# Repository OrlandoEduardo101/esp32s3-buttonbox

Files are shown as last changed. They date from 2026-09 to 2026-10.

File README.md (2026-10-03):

🇧🇷 Português | [🇺🇸 English](README.en.md)

# ESP32-S3 SimHub Button Box

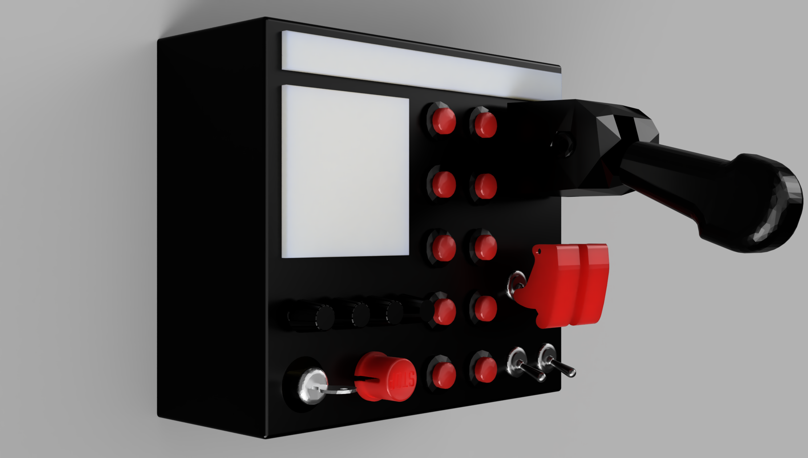
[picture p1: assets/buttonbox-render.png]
Render do button box


Button box open source (firmware + case impresso em 3D) pra sim racing:
USB HID gamepad nativo, WiFi + OTA, e integração real com o SimHub — a
placa aparece pro SimHub como um "Arduino" padrão, e **todos os efeitos de
luz são configurados dentro do próprio SimHub**, sem precisar escrever
nenhum comportamento de jogo no firmware.

## O que é este projeto

Um button box completo, do hardware ao firmware, com duas partes:

1. **Eletrônica + firmware** (este repositório): uma ESP32-S3 lê até 31
   controles físicos (botões, encoders, ignição, chaves, freio de
   estacionamento) e os expõe como um gamepad USB padrão, ao mesmo tempo
   em que fala o protocolo real do SimHub pela mesma porta serial pra
   controlar uma matriz de LEDs 8x8 (ex.: bandeiras/iFlag) e uma fita de
   LEDs (ex.: RPM).
2. **Case impresso em 3D** (pasta [`assets/`](assets)): o invólucro físico
   completo, mais pontos de fixação pra encaixar acessórios impressos por
   terceiros (freio de estacionamento, botão de rádio PTT) — ver seção
   abaixo.

## Recursos principais

- **HID nativo** (USB-OTG/TinyUSB) — aparece como gamepad no Windows sem
  driver nenhum, 32 botões.
- **WiFi + OTA** — depois da primeira gravação por cabo, todo o resto é
  sem fio.
- **Protocolo Arduino real do SimHub** — incluindo a camada de transporte
  ARQ (checksum + confirmação por pacote) que o scanner da aba "Arduino"
  do SimHub realmente usa, não um sketch de LED simplificado.
- **RGB Matrix (8x8) + RGB Leds (fita)** — dois dispositivos lógicos
  separados pro SimHub, numa única cadeia física de LEDs endereçáveis.
  Nenhuma lógica de jogo no firmware: o SimHub decide as cores, o
  firmware só recebe e acende.
- **Pinout 100% centralizado e configurável** — trocar de placa ESP32 ou
  reaproveitar este projeto com outro pinout é editar um arquivo só (ver
  abaixo).
- **Sem matriz de botões** — cada entrada tem canal/pino próprio,
  priorizando confiabilidade e simplicidade de fiação.
- **Case open source** — impresso em 3D, com pontos pra parafusar
  acessórios de terceiros.

## Hardware eletrônico

| Componente | Função |
|---|---|
| ESP32-S3 (qualquer variante com USB-OTG nativo) | MCU — HID, WiFi, OTA, protocolo SimHub |
| MCP23017 (I2C) | CLK/DT dos 4 encoders (quadratura, amostrada 1 kHz), SW dos 4 encoders, 4 chaves "caça" |
| 74HC4067 (mux 16 canais) | 11 push buttons, ignição (3 posições), botão Start Engine, freio de estacionamento |
| 4× encoder KY-040 | CLK/DT e SW pelo MCP23017 (nenhum fio direto na MCU) |
| Matriz WS2812 8x8 (64 LEDs) | RGB Matrix do SimHub — ex.: iFlag |
| Fita WS2812 (~12 LEDs, configurável) | RGB Leds do SimHub — ex.: RPM |

## Case impresso em 3D

Tudo em [`assets/`](assets):

| Arquivo | Conteúdo |
|---|---|
| `assets/STL/front.stl` | Painel frontal |
| `assets/STL/rear.stl` | Painel traseiro |
| `assets/STL/stand.stl` | Base/suporte |
| `assets/STL/LED holder.stl` | Suporte da matriz/fita de LED |
| `assets/buttonbox.f3z` | Projeto Fusion 360 completo, editável (arquivo grande — ver nota abaixo) |

> **Nota sobre o `buttonbox.f3z`**: esse arquivo tem ~124 MB, acima do
> limite de 100 MB que o GitHub aceita sem Git LFS configurado no
> repositório. Ele ainda não está versionado aqui — se você precisar do
> projeto Fusion 360 editável, pergunte ou acompanhe o repositório pra
> essa parte ser resolvida (Git LFS, ou hospedagem externa).

### Acessórios de terceiros compatíveis

Estes não são meus — são projetos separados de outros criadores, feitos
pra combinar com este button box. Baixe, imprima e parafuse direto no
case:

- **[Freio de estacionamento DIY para truck simulators](https://www.printables.com/model/995554-diy-parking-brake-for-truck-simulators/files)**
  (Printables) — a alavanca física que aciona o `INPUT_HANDBRAKE`
  (ver [`docs/INPUTS_PINOUT.md`](docs/INPUTS_PINOUT.md) seção 7 pra como o
  firmware trata esse sinal).
- **Botão de rádio (PTT)** — duas opções no Thingiverse:
  [thing:4740146](https://www.thingiverse.com/thing:4740146) e
  [thing:2928122](https://www.thingiverse.com/thing:2928122).

Confira a licença e os créditos de cada modelo na própria página do
autor antes de usar/redistribuir.

## Por que dá pra reaproveitar isso pra outra placa/pinout

Todo pino, canal e endereço deste projeto está centralizado em
**[`include/board_config.h`](include/board_config.h)** — é o único arquivo
que muda se você trocar de placa ESP32 (maior, outra variante) ou só
quiser usar pinos diferentes. Nenhum outro `.cpp`/`.h` tem número de pino
"solto" no meio do código.

Os drivers de cada componente (`lib/mcp23017`, `lib/mux4067`,
`lib/encoders`, `lib/ws2812`) são genéricos e continuam funcionando
sozinhos, fora deste projeto — cada um aceita pino/endereço como parâmetro
e só usa um valor default próprio se você não passar nada.

## Arquitetura (visão geral)

```
                    ESP32-S3
                       │
        ┌──────────────┼───────────────┐
        │              │               │
       HID            CDC             WiFi
        │              │               │
        │           SimHub            OTA
        │              │
        │         RGB framebuffer
        │              │
        │              ▼
        │           WS2812 (matriz + fita, em série)
        │
        ▼
      INPUTS
        │
   Expansores (task dedicada faz o polling)
   ┌────┴────┐
   │         │
MCP23017   74HC4067
   │         │
   └─────────┴── controles físicos
```

Cada seta é uma camada independente — nenhuma conhece a lógica da outra
(ex.: o driver WS2812 não sabe o que é RPM; o parser do SimHub não sabe o
que é GPIO). Detalhe completo, com a auditoria de cada regra de
isolamento, em [`docs/SYSTEM_INTEGRATION.md`](docs/SYSTEM_INTEGRATION.md).

## Como compilar e gravar

1. **`secrets.h`** (obrigatório, não versionado — só o hostname OTA, sem
   WiFi):
   ```
   cp include/secrets.h.example include/secrets.h
   ```
   Não precisa editar nada pra WiFi funcionar — ver o passo 4 abaixo.

2. **Pinout** (só se sua fiação for diferente do padrão): edite
   [`include/board_config.h`](include/board_config.h).

3. **Compilar + gravar por USB** (primeira vez, ou sem WiFi disponível):
   ```
   pio run -e esp32s3-supermini -t upload
   ```
   Não precisa segurar nenhum botão — o firmware entra em modo download
   sozinho (ver `scripts/enter_bootloader.py`).

4. **Configurar o WiFi** (nenhuma credencial fica no código/repositório):
   segure o botão **BOOT** da placa por 5s — ou, com a caixa fechada,
   **Push button 1 + Push button 2** juntos por 5s. Abre um Access Point
   `ButtonBox-Setup`; conecta nele do celular/PC e escolhe a rede. Fica
   salvo no NVS da própria placa, sobrevive a reboot. Pode repetir esse
   gesto a qualquer momento pra trocar de rede (ex.: levou a button box pra
   outra casa).

5. **Gravar por OTA** (depois da primeira vez, com WiFi já configurado):
   ```
   pio run -e ota -t upload
   ```

## Como testar cada peça isoladamente

Cada componente de hardware tem um firmware de teste próprio, sem HID/
WiFi/OTA/SimHub misturado — grava, conecta só aquele componente, e
confirma que funciona antes de integrar com o resto:

| Env | Testa | Comando |
|---|---|---|
| `mcp-test` | MCP23017 (16 entradas) | `pio run -e mcp-test -t upload -t monitor` |
| `mux-test` | 74HC4067 (canais configurados) | `pio run -e mux-test -t upload -t monitor` |
| `encoder-test` | Os 4 KY-040 (CW/CCW) | `pio run -e encoder-test -t upload -t monitor` |
| `inputs-test` | Camada unificada (os três juntos) | `pio run -e inputs-test -t upload -t monitor` |
| `ws2812-test` | Matriz + fita (varredura de cores) | `pio run -e ws2812-test -t upload -t monitor` |
| `simhub-test` | Protocolo SimHub isolado | `pio run -e simhub-test -t upload` + `python scripts/simhub_test_send.py <porta>` |
| `diag` | Toolchain/board mínimo (sem HID) | `pio run -e diag -t upload -t monitor` |

Se o firmware completo (`esp32s3-supermini`) apresentar algum problema,
comece isolando pelo teste do componente suspeito — é mais rápido achar a
causa assim do que depurar tudo junto.

## Console serial (CDC)

Além do protocolo do SimHub, a mesma porta COM aceita comandos de texto
(qualquer terminal serial, 115200 baud):

| Comando | Efeito |
|---|---|
| `PING` | responde `PONG` |
| `VERSION` | versão do firmware |
| `IP` | IP atual na rede |
| `SETLEDS <n>` | define quantos LEDs tem a fita (persiste em NVS) |
| `DUMPLEDS` | mostra o que os framebuffers da matriz/fita têm agora |
| `BOOTLOADER` | entra em modo download por software (sem precisar do botão BOOT) |

## Documentação completa

| Arquivo | Conteúdo |
|---|---|
| [`docs/ARCHITECTURE.md`](docs/ARCHITECTURE.md) | USB (VID/PID/descriptors), HID, CDC, WiFi, OTA — como cada peça do baseline funciona |
| [`docs/BASELINE.md`](docs/BASELINE.md) | Testes que comprovadamente passaram, com evidência |
| [`docs/INPUTS_PINOUT.md`](docs/INPUTS_PINOUT.md) | Por que cada entrada foi pro MCP23017/74HC4067/GPIO direto (o raciocínio; os números atuais estão em `board_config.h`) |
| [`docs/SIMHUB_PROTOCOL.md`](docs/SIMHUB_PROTOCOL.md) | Protocolo real do SimHub (transporte ARQ + comandos), com os erros de investigação registrados de propósito |
| [`docs/SYSTEM_INTEGRATION.md`](docs/SYSTEM_INTEGRATION.md) | Integração final, auditoria de isolamento entre camadas, checklist de teste completo |
| [`HANDOFF.md`](HANDOFF.md) | Histórico do projeto (incluindo a tentativa anterior com STM32, abandonada por hardware clonado) |

## Não implementado por decisão explícita

- Nenhuma lógica de jogo no firmware (RPM, flags, shift light, pit
  limiter) — o SimHub decide tudo, o firmware só recebe RGB e acende.
- `SHCustomProtocol` do SimHub — não usado; a placa aparece como um
  dispositivo "Arduino" padrão, configurável inteiramente pela UI do
  SimHub.
- Matriz de botões — cada entrada tem canal/pino próprio.

## ☕ Apoie este projeto

Se este projeto te ajudou ou economizou seu tempo, você pode apoiar:

- PicPay: **@orlandoeduardo.pereira**
- Link: https://picpay.me/orlandoeduardo.pereira
- Link (PicPay): https://link.picpay.com/p/177377918669b9b8f2b4e25

QR Code PIX:

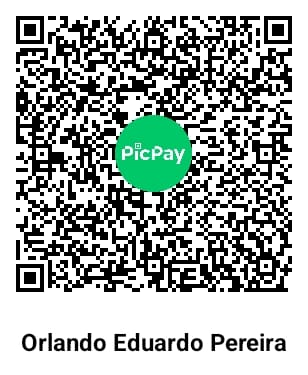
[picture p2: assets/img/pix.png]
QR Code PIX do PicPay


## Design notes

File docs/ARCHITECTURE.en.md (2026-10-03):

[🇧🇷 Português](ARCHITECTURE.md) | 🇺🇸 English

# ARCHITECTURE.md — Verified current state (post-stage-5 baseline)

> This document describes the firmware **exactly as it exists right now**, with
> no code changes made during this audit. Every fact here is
> verified by direct reading of this project's source code, of the installed
> Arduino-ESP32 core (`~/.platformio/packages/framework-arduinoespressif32`)
> and/or of `compile_commands.json` (macros actually used in the last
> compilation) — never by assumption or by trusting the Windows screen alone
> (which can have stale driver cache, as we've seen before).
>
> Generated on 2026-09-15. If the code changes after this date, this document
> may become outdated — treat it as a snapshot, not a live source.

---

## 1. How the device shows up in Windows

When connected via USB, Windows enumerates **a single composite USB device**
with two functions (interfaces), recognized by two different drivers:

- **`joy.cpl` (Game controllers)**: shows up as `ESP32S3-SimHub-ButtonBox`,
  status OK, with **32 buttons** and **4 axes** (X, Y, Z, Z-Rotation, X-Rotation,
  Y-Rotation — 6 axes declared in the descriptor, but `main.cpp` only uses the
  button bitmask; axes always stay at 0). Button 32 blinks on its own
  The Button 32 is free — the heartbeat that used to blink on it was removed
  (see item 9).
- **COM port (Device Manager → Ports)**: shows up with the same
  product name, assigned by Windows' standard serial driver (`usbser.sys`),
  usable from any serial terminal (VS Code Serial Monitor, PuTTY, etc.) at
  115200 baud.

Confirmed by a real screenshot from the user (joy.cpl with 32 dots, button
32 lit) and by a Serial Monitor session responding to text commands.

## 2. VID/PID

- **VID = `0x303A`** (Espressif Systems) — fixed, comes from the core (`USB_ESPRESSIF_VID`
  in `esp32-hal-tinyusb.h`), never overridden in this project.
- **PID = `0x1001`** — comes from `variants/esp32s3/pins_arduino.h`
  (`#define USB_PID 0x1001`), which is included **before** the fallback in
  `USB.cpp` (`#ifndef USB_PID #define USB_PID 0x0002`). Since this project's
  board.json uses `"variant": "esp32s3"`, the variant's define wins and the
  app enumerates as **`303A:1001`**.

  > **CORRECTION (2026-09-16).** The previous version of this document claimed
  > the PID was `0x0002` and that any `303A:1001` seen in a `device
  > list` would be "the separate USB-Serial-JTAG interface". **Both
  > claims were wrong.** The mistake came from checking only
  > `compile_commands.json` (where indeed there's no `-DUSB_PID`) and concluding
  > from that, without checking the variant's header. Practical consequence:
  > seeing `303A:1001` on a port does **not** mean the board is in
  > bootloader mode — it's the app running normally.

## 3. Manufacturer

`SimRacing_DIY` — explicitly defined in `platformio.ini`:
```
-DUSB_MANUFACTURER=\"SimRacing_DIY\"
```
Without this flag, the core would use the default `"Espressif Systems"`.

## 4. Product

`ESP32S3-SimHub-ButtonBox` — explicitly defined in `platformio.ini`:
```
-DUSB_PRODUCT=\"ESP32S3-SimHub-ButtonBox\"
```
Without this flag, the core would default to the `ARDUINO_BOARD` macro, which
PlatformIO automatically injects from the `"name"` field in
`boards/esp32-s3-fh4r2.json` (`"ESP32-S3-FH4R2 (Dingyimei S3 Zero)"`) — this was
exactly the leak that caused the odd name in `joy.cpl` before this
fix (already applied and confirmed, part of the current baseline).

## 5. Serial Number

Not fixed in code — it's **automatically derived from the chip's MAC address**
at runtime. Mechanism (`USB.cpp`, `ESPUSB::begin()`):
```
USB_SERIAL default = "__MAC__"
  -> if (serial_number == "__MAC__"): reads esp_efuse_mac_get_default(),
     formats as "%02X%02X%02X%02X%02X%02X" (12 uppercase hex chars)
```
For the board used in testing (MAC `AC:27:6E:CC:FA:B8`), the observed serial is
`AC276ECCFAB8` — matches the formula above exactly.

`platformio.ini` also uses this MAC (`custom_expected_mac`,
`custom_board_mac`) for the port auto-detection scripts — see items 12
and 15.

## 6. USB Interfaces

Composite TinyUSB device with `ARDUINO_USB_MODE=0` (native USB-OTG) and
`ARDUINO_USB_CDC_ON_BOOT=1`:

- **HID interface** — HID class, one interrupt IN endpoint. Gamepad
  reports (see item 7).
- **CDC ACM interface** (2 sub-interfaces: Control + Data, like any standard
  TinyUSB CDC) — virtual serial port, used for text commands and
  logs (see item 10).

There's no hand-written composite descriptor in this project (unlike
the earlier STM32 project, where `usb_descriptors.c` assembled everything manually) —
here the Arduino-ESP32 core assembles the descriptor automatically based on which
classes (`USB.begin()`, `USBHIDGamepad`, `USBCDC` via `ARDUINO_USB_CDC_ON_BOOT`)
get initialized in `setup()`.

## 7. HID report descriptor

Comes ready-made from the Arduino-ESP32 core (`libraries/USB/src/USBHIDGamepad.cpp`), via
TinyUSB's standard template:
```c
static const uint8_t report_descriptor[] = {
    TUD_HID_REPORT_DESC_GAMEPAD(HID_REPORT_ID(HID_REPORT_ID_GAMEPAD))
};
```
Not a single byte of this descriptor is customized in this project — it's TinyUSB's
standard `TUD_HID_REPORT_DESC_GAMEPAD` template (`class/hid/hid_device.h`), with
**Report ID = 3** (`HID_REPORT_ID_GAMEPAD`, the 4th value in the enum
`HID_REPORT_ID_NONE=0, KEYBOARD=1, MOUSE=2, GAMEPAD=3` in `USBHID.h`).

Report layout (`hid_gamepad_report_t` struct, 8 bytes + 1 Report ID byte):

| Field | Size | Type | Use in firmware |
|---|---|---|---|
| Report ID | 1 byte  | — | always `3`, implicit |
| X | 1 byte  | int8 | always `0` (unused) |
| Y | 1 byte  | int8 | always `0` (unused) |
| Z | 1 byte  | int8 | always `0` (unused) |
| Rz | 1 byte  | int8 | always `0` (unused) |
| Rx | 1 byte  | int8 | always `0` (unused) |
| Ry | 1 byte  | int8 | always `0` (unused) |
| Hat/DPad  | 1 byte  | uint8  | always `0` (centered, unused)  |
| Buttons | 4 bytes | uint32 | bitmask, bit N = button N+1 |

`main.cpp` only uses the last field:
```cpp
Gamepad.send(0, 0, 0, 0, 0, 0, 0, buttons);
//           x  y  z  rz rx ry hat  buttons
```
The 6 axes and the hat exist because they're part of TinyUSB's fixed template —
there's no way to omit them without writing a custom descriptor (which this
project doesn't do). That's why `joy.cpl` shows axes parked at zero.

## 8. Number of buttons currently exposed

**UPDATED** since the original version of this document (2026-09-15): the
unified `lib/inputs` layer was integrated into HID, replacing the
simulated values. **32 buttons** in the descriptor (`uint32_t buttons`, bits
0–31, `HID_REPORT_COUNT(32)`, unchanged), of which:

- **Bits 0–30 (Buttons 1–31)** = the 31 real Button Box controls
  (MCP23017 + 74HC4067 + 4× KY-040), via `lib/inputs`. Full map
  (INPUT LOGICAL ID → bit) in `docs/INPUTS_PINOUT.en.md` section 10.
- **Bit 31 (Button 32)** = **free**. It used to be the bring-up heartbeat,
  removed as soon as the 31 real controls started responding on the bench. It
  is the first slot available for a new control.

The old "Bit 0 = board's BOOT button" was removed — it was a
simulated bring-up value, replaced by the real `INPUT_BUTTON_01` (MCP23017).
The physical BOOT button still exists only to open the WiFi portal
(hold for 5s), with no more connection to HID.

## 9. The button-32 heartbeat — removed

**It no longer exists in the firmware.** Throughout bring-up, bit 31 toggled on
its own every 1 s, purely in software via `millis()`, with no dependency on
WiFi/OTA/interrupts and no wiring at all:

```cpp
// REMOVED — kept here only as a reusable technique
if (now - lastBeatMs >= 1000) {
  lastBeatMs = now;
  beatOn = !beatOn;
  if (beatOn) buttons |= (1UL << 31);
  else        buttons &= ~(1UL << 31);
}
```

It was a proof of life for the HID before any hardware existed: if Button 32
blinked in `joy.cpl`, then USB, the descriptor and report sending were fine, and
any problem was wiring.

It went away once the 31 real controls started responding. Keeping it would be
noise: a button that fires by itself every second is exactly the kind of thing a
game or SimHub binds by mistake during auto-learn.

It is worth pasting the snippet back temporarily when bringing up a **new
board** — it is the cheapest test there is, and needs nothing soldered.

## 10. How the CDC is used

The CDC (COM port) is used only for a simple line-by-line text console,
processed in `serialCommands()`:

| Command | Response / effect |
|---|---|
| `PING` | replies `PONG` |
| `VERSION` | replies `ESP32S3_BUTTONBOX_HID_OTA` |
| `IP` | replies with the current IP (`WiFi.localIP()`) |
| `RSSI` | replies `RSSI <dBm> sleep=<ON\|OFF> ip=<ip>`, or `RSSI_OFFLINE`. Link diagnostic: `-50` great, `-67` is the practical floor for reliable OTA, below `-75` OTA breaks. `sleep=ON` together with a flaky OTA is a firmware bug, not a network one |
| `SETLEDS <n>`| sets the number of LEDs on the **strip** (1-192, default 12; the matrix is fixed at 64). Persisted in NVS. Replies `LEDS_SET <n>` or `LEDS_INVALID (1-192)` |
| `BRIGHTNESS` | replies `BRIGHTNESS_GET <n>%` (query only) |
| `BRIGHTNESS <n>` | caps global LED brightness. Clamped to 25-75%, so `BRIGHTNESS 10` replies `BRIGHTNESS_SET 25%` without an error; it only rejects outside 1-100. Persisted in NVS |
| `DUMPLEDS` | prints what arrived from SimHub (matrix and strip) without needing the physical LEDs lit |
| `WATCH` | toggles input-transition logging. Every press prints the **logical name** of the `InputId` (e.g. `[watch] INPUT_BUTTON_03  PRESSIONADO`). Use it to find a swapped wire without a multimeter: pressing button 4 and getting `INPUT_BUTTON_03` proves the wire is on the wrong channel. Off by default |
| `LED` | shows `gpio`, `override` and the ignition state the firmware reads |
| `LED 1` / `LED 0` | forces the Start Engine LED, ignoring the key — isolates firmware from wiring |
| `LED AUTO` | hands LED control back to the ignition |
| `BOOTLOADER` | replies `REBOOTING_TO_BOOTLOADER`, then enters download mode via `usb_persist_restart(RESTART_BOOTLOADER)` — see item 15 for why this is **no longer** a direct `REG_WRITE` |

It also emits periodic unsolicited logs (`statusReport()`, every 5s):
WiFi/OTA/portal status. **During an OTA upload (`otaRunning == true`), the CDC
is not used for anything** — no writes happen, on purpose (see item 12).

Commands are case-insensitive (converted to uppercase before `strcmp`),
terminated by `\n` (32-byte buffer, `\r` ignored).

## 11. How WiFi connects

**No hardcoded credential (changed Oct/2026).** Always station mode (STA),
but `WiFi.begin()` is called **with no arguments** — this reconnects to the
last network saved in the ESP32's own NVS (persisted automatically on every
successful `WiFi.begin(ssid, pass)`, including what the config portal does
internally). On a never-configured board this simply doesn't connect (empty
NVS) until someone opens the portal once — deliberate: no network is fixed
in the firmware or the repo, so anyone reusing this project (or moving
houses/networks, as actually happened in practice) configures their own
network through the portal alone, with no code or `secrets.h` edit:

```cpp
// setup()
WiFi.mode(WIFI_STA);
WiFi.setAutoReconnect(true);
WiFi.begin(); // last network saved in NVS, no credential in the code
```

If the connection drops or never comes up, `wifiKeepAlive()` (called every
`loop()`, but throttled to 1 attempt every 10s) calls `WiFi.disconnect()` +
`WiFi.begin()` again (same no-argument call), **forever, without giving up
and without opening the portal on its own**. This is deliberate (comment at
the top of `main.cpp`): an earlier version opened the config portal
automatically on every failure and the board got stuck in AP mode, offline,
never reconnecting again.

The config portal (`WiFiManager`, for switching/registering the network
without recompiling or editing `secrets.h`) only opens on explicit request,
**two** ways:
- holding the board's **BOOT** button for 5 seconds **during normal
  operation** (not at boot — GPIO0 low at reset enters download mode and
  the app never even runs);
- with the **case closed** (no access to BOOT): holding **Push button 1 +
  Push button 2** together for 5 seconds. Any button combo works as long as
  it doesn't include Push button 11 (it's the radio PTT — pressed
  frequently during normal use, can't be part of a "hold for 5s" gesture).

```cpp
// src/main.cpp — same function for both gestures
static void startWifiPortal() {
  wm.setConfigPortalBlocking(false);
  wm.startConfigPortal(AP_NAME);  // AP_NAME = "ButtonBox-Setup"
  portalAtivo = true;             // do NOT use the return value — see note below
}
```

**Bug fixed (Oct/2026):** `startConfigPortal()` in non-blocking mode always
returns `false` immediately (it only enters the blocking loop when
configured blocking, which isn't the case here). Assigning that return
value directly to `portalAtivo` made `loop()` never call `wm.process()` —
the portal's AP would come up (SSID visible) but the config page never
responded, because the DNS/HTTP handler only runs inside `wm.process()`.
Now `portalAtivo` is set to `true` unconditionally, and only goes back to
`false` once `wm.process()` returns `true` (new network connected
successfully).

`WiFi.setSleep(false)` is only called inside `startOta()`, **after**
`WiFi.begin()` has already been called in `setup()` — calling it before, with the
radio not yet initialized in STA, prevents the AP portal from coming up (a lesson
documented at the top of the file).

## 12. How OTA is started

`ArduinoOTA` + `ESPmDNS`, initialized once by `startOta()`,
called from `loop()` only when WiFi is connected:
```cpp
void loop() {
  if (WiFi.status() == WL_CONNECTED) startOta();
  if (otaReady) ArduinoOTA.handle();
  if (otaRunning) return;   // nothing else runs during upload
  ...
}
```
`startOta()` is guarded by `otaReady` (only runs once): registers the hostname
(`OTA_HOSTNAME`, from `secrets.h`), `onStart`/`onEnd`/`onError` callbacks, and
**deliberately no `onProgress` callback** — writing to the CDC during
the upload blocks when the host isn't reading the port, which used to stall
`ArduinoOTA.handle()` and kill the transfer halfway through (this was the cause of
the old "Error Uploading" at ~29%, resolved before this baseline).

Once the OTA upload starts (`otaRunning = true` in `onStart`), the
`loop()` returns early right after calling `ArduinoOTA.handle()` — no
other logic (HID, serial, WiFi keep-alive) runs until the upload finishes.

## 13. How the firmware is updated

Two paths, both via the same `platformio.ini`:

- **USB (cable)**: `pio run -e esp32s3-supermini -t upload`. The
  `extra_scripts = pre:scripts/enter_bootloader.py` runs before the upload:
  finds the board's port by MAC (`custom_expected_mac`), opens it with
  `dtr=False, rts=False`, sends `BOOTLOADER\n` (the same command from item 10),
  waits up to 10s for a new port in download mode, and repoints
  `UPLOAD_PORT` to it. **Doesn't require manually holding the BOOT button** —
  this was already a problem resolved before this baseline.
- **OTA (WiFi)**: `pio run -e esp32s3-ota -t upload` (env `[env:ota]`, which
  extends `esp32s3-supermini` with `upload_protocol = espota`). The
  `extra_scripts = pre:scripts/ota_port_by_mac.py` discovers the board's current
  IP by MAC (`arp -a` after a broadcast ping) and replaces
  `UPLOAD_PORT` with it — works around the fact that `espota` doesn't resolve
  `.local` (mDNS) names and the IP can change via DHCP.

In both cases, the binary is uploaded to the idle OTA partition (`ota_0`/`ota_1`,
1.25 MB each, see `default.csv`) and the bootloader switches to it on the next
boot — there's no need to erase the entire flash.

## 14. Which PlatformIO board/env should be used

- **Board**: `esp32-s3-fh4r2` (`boards/esp32-s3-fh4r2.json`, custom, **not** the
  generic `esp32-s3-devkitc-1`) — 4 MB flash + 2 MB quad PSRAM
  (`memory_type=qio_qspi`), `default.csv` partitions. Using the generic devkit
  (8 MB, without this PSRAM) causes a **boot loop** on this physical board (history
  documented in `HANDOFF.md`).
- **Env for normal development (compile + flash + run)**:
  `[env:esp32s3-supermini]` — the only one with the production firmware
  (`src_filter = +<main.cpp>`), full HID + CDC + WiFi + OTA.
- **`[env:diag]` env**: an alternative minimal firmware (`src/diag.cpp`,
  `ARDUINO_USB_MODE=1`, just prints `"alive N"` every 500 ms). Exists only to
  isolate toolchain/board/flashing problems from the HID logic — **not the
  product firmware**, exposes no HID at all.
- **`[env:ota]` env**: the same firmware as `esp32s3-supermini` (via `extends`),
  just swaps the upload protocol to WiFi.

## 15. Which files are critical and shouldn't be changed without need

| File | Why it's critical |
|---|---|
| `src/main.cpp` | All the HID, WiFi, OTA, and serial console logic. Contains, in comments at the top and around the `BOOTLOADER` command, the history of already-resolved bugs (stuck portal, `setSleep` before `begin`, CDC writes stalling OTA, RTC register stuck in bootloader) — removing those comments or undoing those decisions reintroduces already-fixed bugs. |
| `platformio.ini` | `board_build.extra_flags` with `ARDUINO_USB_MODE=0` is what turns on HID (the board.json defaults to `MODE=1`, which **doesn't do HID**). `-DBOARD_HAS_PSRAM` is what fixes OTA's `Flash Read Failed`. `-DUSB_PRODUCT`/`-DUSB_MANUFACTURER` prevent the board.json name from leaking into the USB descriptor. `upload_speed=115200` is deliberate (a higher speed fails esptool's handshake over TinyUSB's CDC). |
| `boards/esp32-s3-fh4r2.json` | Custom board definition (4 MB flash + PSRAM); swapping it for a generic board already caused a boot loop in the past. |
| `scripts/enter_bootloader.py` | Mechanism that allows USB flashing without manually pressing the BOOT button; depends on the `BOOTLOADER` command in `main.cpp` using `usb_persist_restart()` (not the direct RTC register). |
| `scripts/ota_port_by_mac.py` | Mechanism that lets `espota` find the board without a fixed IP or working mDNS. |
| `include/secrets.h` | Just the OTA hostname (`OTA_HOSTNAME`) — WiFi no longer lives here, see section 11. Git-ignored — should never be committed or have its contents printed/logged. |
| `~/.platformio/packages/framework-arduinoespressif32` (installed core) | Not part of this project, but the USB/HID/CDC behavior described here depends on the installed version (`espressif32@6.12.0` / `framework-arduinoespressif32@3.20017.241212`, see `docs/BASELINE.md`). A core update could change defaults (e.g. `USB_PID`, HID report layout). |

**Not** a critical file, free for exploratory use: `src/diag.cpp` (isolated
diagnostic env, doesn't affect the production firmware).

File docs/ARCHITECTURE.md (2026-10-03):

🇧🇷 Português | [🇺🇸 English](ARCHITECTURE.en.md)

# ARCHITECTURE.md — Estado atual verificado (baseline pós-etapa 5)

> Este documento descreve o firmware **exatamente como ele existe agora**, sem
> nenhuma alteração de código feita durante esta auditoria. Todo fato aqui é
> verificado por leitura direta do código-fonte deste projeto, do core
> Arduino-ESP32 instalado (`~/.platformio/packages/framework-arduinoespressif32`)
> e/ou de `compile_commands.json` (macros efetivamente usadas na última
> compilação) — não por suposição nem só pela tela do Windows (que pode ter
> cache de driver, como já vimos no passado).
>
> Gerado em 2026-09-15. Se o código mudar depois desta data, este documento
> pode ficar desatualizado — trate-o como uma fotografia, não como fonte viva.

---

## 1. Como o dispositivo aparece no Windows

Ao conectar via USB, o Windows enumera **um único dispositivo USB composto**
com duas funções (interfaces), reconhecidas por dois drivers diferentes:

- **`joy.cpl` (Controladores de jogo)**: aparece como `ESP32S3-SimHub-ButtonBox`,
  status OK, com **32 botões** e **4 eixos** (X, Y, Z, Rotação Z, Rotação X,
  Rotação Y — 6 eixos declarados no descriptor, mas o `main.cpp` só usa o
  bitmask de botões; eixos ficam sempre em 0). O Botão 32 está livre — o
  heartbeat que piscava nele foi removido (ver item 9).
- **Porta COM (Gerenciador de Dispositivos → Portas)**: aparece com o mesmo
  nome de produto, atribuída pelo driver serial padrão do Windows (`usbser.sys`),
  usável em qualquer terminal serial (VS Code Serial Monitor, PuTTY, etc.) a
  115200 baud.

Confirmado por captura de tela real do usuário (joy.cpl com 32 pontos, botão
32 aceso) e por sessão de Serial Monitor respondendo aos comandos de texto.

## 2. VID/PID

- **VID = `0x303A`** (Espressif Systems) — fixo, vem do core (`USB_ESPRESSIF_VID`
  em `esp32-hal-tinyusb.h`), nunca sobrescrito neste projeto.
- **PID = `0x1001`** — vem de `variants/esp32s3/pins_arduino.h`
  (`#define USB_PID 0x1001`), que é incluído **antes** do fallback do
  `USB.cpp` (`#ifndef USB_PID #define USB_PID 0x0002`). Como o board.json
  deste projeto usa `"variant": "esp32s3"`, o define do variant vence e o
  app enumera como **`303A:1001`**.

  > **CORREÇÃO (2026-09-16).** A versão anterior deste documento afirmava
  > que o PID era `0x0002` e que qualquer `303A:1001` visto em `device
  > list` seria "a interface USB-Serial-JTAG separada". **As duas
  > afirmações estavam erradas.** O erro veio de verificar só o
  > `compile_commands.json` (onde de fato não há `-DUSB_PID`) e concluir
  > dali, sem checar o header do variant. Consequência prática: ver
  > `303A:1001` numa porta **não** significa que a placa está em modo
  > bootloader — é o app rodando normalmente.

## 3. Manufacturer

`SimRacing_DIY` — definido explicitamente em `platformio.ini`:
```
-DUSB_MANUFACTURER=\"SimRacing_DIY\"
```
Sem essa flag, o core usaria o default `"Espressif Systems"`.

## 4. Product

`ESP32S3-SimHub-ButtonBox` — definido explicitamente em `platformio.ini`:
```
-DUSB_PRODUCT=\"ESP32S3-SimHub-ButtonBox\"
```
Sem essa flag, o core usaria como default a macro `ARDUINO_BOARD`, que o
PlatformIO injeta automaticamente a partir do campo `"name"` de
`boards/esp32-s3-fh4r2.json` (`"ESP32-S3-FH4R2 (Dingyimei S3 Zero)"`) — foi
exatamente esse vazamento que causava o nome estranho no `joy.cpl` antes desta
correção (já aplicada e confirmada, faz parte da baseline atual).

## 5. Serial Number

Não é fixo no código — é **derivado automaticamente do endereço MAC** do chip
em tempo de execução. Mecanismo (`USB.cpp`, `ESPUSB::begin()`):
```
USB_SERIAL default = "__MAC__"
  -> if (serial_number == "__MAC__"): lê esp_efuse_mac_get_default(),
     formata como "%02X%02X%02X%02X%02X%02X" (12 chars hex maiúsculos)
```
Para a placa usada nos testes (MAC `AC:27:6E:CC:FA:B8`), o serial observado é
`AC276ECCFAB8` — bate exatamente com a fórmula acima.

`platformio.ini` também usa esse MAC (`custom_expected_mac`,
`custom_board_mac`) para os scripts de auto-detecção de porta — ver itens 12
e 15.

## 6. Interfaces USB

Dispositivo composto TinyUSB com `ARDUINO_USB_MODE=0` (USB-OTG nativo) e
`ARDUINO_USB_CDC_ON_BOOT=1`:

- **Interface HID** — classe HID, um endpoint IN de interrupt. Relatórios de
  gamepad (ver item 7).
- **Interface CDC ACM** (2 sub-interfaces: Control + Data, como todo CDC
  padrão TinyUSB) — porta serial virtual, usada para os comandos de texto e
  logs (ver item 10).

Não há descriptor de composite escrito à mão neste projeto (diferente do
projeto STM32 anterior, onde `usb_descriptors.c` montava tudo manualmente) —
aqui o core Arduino-ESP32 monta o descriptor automaticamente a partir de quais
classes (`USB.begin()`, `USBHIDGamepad`, `USBCDC` via `ARDUINO_USB_CDC_ON_BOOT`)
são inicializadas em `setup()`.

## 7. HID report descriptor

Vem pronto do core Arduino-ESP32 (`libraries/USB/src/USBHIDGamepad.cpp`), via
o template padrão do TinyUSB:
```c
static const uint8_t report_descriptor[] = {
    TUD_HID_REPORT_DESC_GAMEPAD(HID_REPORT_ID(HID_REPORT_ID_GAMEPAD))
};
```
Nenhum byte desse descriptor é customizado neste projeto — é o template padrão
`TUD_HID_REPORT_DESC_GAMEPAD` do TinyUSB (`class/hid/hid_device.h`), com
**Report ID = 3** (`HID_REPORT_ID_GAMEPAD`, 4º valor do enum
`HID_REPORT_ID_NONE=0, KEYBOARD=1, MOUSE=2, GAMEPAD=3` em `USBHID.h`).

Layout do report (struct `hid_gamepad_report_t`, 8 bytes + 1 byte de Report ID):

| Campo | Tamanho | Tipo | Uso no firmware |
|---|---|---|---|
| Report ID | 1 byte  | — | sempre `3`, implícito |
| X | 1 byte  | int8 | sempre `0` (não usado) |
| Y | 1 byte  | int8 | sempre `0` (não usado) |
| Z | 1 byte  | int8 | sempre `0` (não usado) |
| Rz | 1 byte  | int8 | sempre `0` (não usado) |
| Rx | 1 byte  | int8 | sempre `0` (não usado) |
| Ry | 1 byte  | int8 | sempre `0` (não usado) |
| Hat/DPad  | 1 byte  | uint8  | sempre `0` (centro, não usado)|
| Buttons | 4 bytes | uint32 | bitmask, bit N = botão N+1 |

`main.cpp` só usa o último campo:
```cpp
Gamepad.send(0, 0, 0, 0, 0, 0, 0, buttons);
//           x  y  z  rz rx ry hat  buttons
```
Os 6 eixos e o hat existem porque fazem parte do template fixo do TinyUSB —
não há como omiti-los sem escrever um descriptor customizado (o que este
projeto não faz). É por isso que o `joy.cpl` mostra eixos parados em zero.

## 8. Quantidade de botões atualmente expostos

**ATUALIZADO** desde a versão original deste documento (2026-09-15): a
camada unificada `lib/inputs` foi integrada ao HID, substituindo os
valores simulados. **32 botões** no descriptor (`uint32_t buttons`, bits
0–31, `HID_REPORT_COUNT(32)`, inalterado), dos quais:

- **Bits 0–30 (Botões 1–31)** = os 31 controles reais da Button Box
  (MCP23017 + 74HC4067 + 4× KY-040), via `lib/inputs`. Mapa completo
  (INPUT LOGICAL ID → bit) em `docs/INPUTS_PINOUT.md` seção 10.
- **Bit 31 (Botão 32)** = **livre**. Era o heartbeat de bring-up, removido
  assim que os 31 controles reais passaram a responder na bancada. É o
  primeiro slot disponível para um controle novo.

O antigo "Bit 0 = botão BOOT da placa" foi removido — era um valor
simulado de bring-up, substituído pelo `INPUT_BUTTON_01` real (MCP23017).
O botão BOOT físico continua existindo só para abrir o portal de WiFi
(segurar 5s), sem mais nenhuma ligação com o HID.

## 9. O heartbeat do botão 32 — removido

**Não existe mais no firmware.** Durante todo o bring-up, o bit 31 alternava
sozinho a cada 1 s, puramente por software/`millis()`, sem depender de
WiFi/OTA/interrupção nem de fiação nenhuma:

```cpp
// REMOVIDO — registrado aqui só como técnica reaproveitável
if (now - lastBeatMs >= 1000) {
  lastBeatMs = now;
  beatOn = !beatOn;
  if (beatOn) buttons |= (1UL << 31);
  else        buttons &= ~(1UL << 31);
}
```

Servia de prova de vida do HID antes de existir hardware: se o Botão 32
piscava no `joy.cpl`, USB, descriptor e envio de report estavam bons, e
qualquer problema era de fiação.

Saiu quando os 31 controles reais passaram a responder. Mantê-lo viraria
ruído: um botão que se aciona sozinho a cada segundo é exatamente o tipo de
coisa que um jogo ou o SimHub bindam por engano num aprendizado automático.

Vale reintroduzir o trecho acima temporariamente ao trazer uma **placa nova**
— é o teste mais barato que existe, e não precisa de nada soldado.

## 10. Como a CDC é usada

A CDC (porta COM) é usada só para um console de texto simples,
linha-a-linha, processado em `serialCommands()`:

| Comando | Resposta / efeito |
|---|---|
| `PING` | responde `PONG` |
| `VERSION` | responde `ESP32S3_BUTTONBOX_HID_OTA` |
| `IP` | responde o IP atual (`WiFi.localIP()`) |
| `RSSI` | responde `RSSI <dBm> sleep=<ON\|OFF> ip=<ip>`, ou `RSSI_OFFLINE`. Diagnóstico de link: `-50` ótimo, `-67` é o piso prático para OTA confiável, `-75` pra baixo o OTA quebra. `sleep=ON` com OTA instável é bug de firmware, não de rede |
| `SETLEDS <n>`| define a quantidade de LEDs **da fita** (1-192, padrão 12; a matriz é fixa em 64). Persiste em NVS. Responde `LEDS_SET <n>` ou `LEDS_INVALID (1-192)` |
| `BRIGHTNESS` | responde `BRIGHTNESS_GET <n>%` (só consulta) |
| `BRIGHTNESS <n>` | limita o brilho global dos LEDs. Grampeado em 25-75%, então `BRIGHTNESS 10` responde `BRIGHTNESS_SET 25%` sem erro; só recusa fora de 1-100. Persiste em NVS |
| `DUMPLEDS` | imprime o que chegou do SimHub (matriz e fita) sem precisar dos LEDs físicos acesos |
| `WATCH` | liga/desliga o log de transições de entrada. Cada aperto imprime o **nome lógico** do `InputId` (ex.: `[watch] INPUT_BUTTON_03  PRESSIONADO`). Serve para achar fio trocado sem multímetro: apertar o botão 4 e sair `INPUT_BUTTON_03` prova que o fio está no canal errado. Desligado por padrão |
| `LED` | mostra `gpio`, `override` e o estado da ignição que o firmware lê |
| `LED 1` / `LED 0` | força o LED do Start Engine, ignorando a chave — isola firmware de fiação |
| `LED AUTO` | devolve o controle do LED para a ignição |
| `BOOTLOADER` | responde `REBOOTING_TO_BOOTLOADER`, depois entra em modo download via `usb_persist_restart(RESTART_BOOTLOADER)` — ver item 15 sobre por que **não** é mais um `REG_WRITE` direto |

Também emite logs periódicos não-solicitados (`statusReport()`, a cada 5 s):
estado do WiFi/OTA/portal. **Durante upload OTA (`otaRunning == true`), a CDC
não é usada para nada** — nenhuma escrita acontece, de propósito (ver item 12).

Comandos são case-insensitive (convertidos para maiúsculo antes do `strcmp`),
terminados por `\n` (buffer de 32 bytes, `\r` ignorado).

## 11. Como o WiFi conecta

**Sem credencial hardcoded (mudou em out/2026).** Modo estação (STA) sempre,
mas `WiFi.begin()` é chamado **sem argumentos** — isso reconecta na última
rede salva no NVS do próprio ESP32 (persistido automaticamente a cada
`WiFi.begin(ssid, pass)` bem-sucedido, inclusive o que o portal de
configuração faz internamente). Numa placa nunca configurada isso
simplesmente não conecta (NVS vazio) até alguém abrir o portal uma vez —
proposital: nenhuma rede fica fixa no firmware nem no repositório, então
qualquer pessoa que reaproveite este projeto (ou troque de casa/rede, como
já aconteceu na prática) configura a rede dela só pelo portal, sem editar
código nem `secrets.h`:

```cpp
// setup()
WiFi.mode(WIFI_STA);
WiFi.setAutoReconnect(true);
WiFi.begin(); // ultima rede salva no NVS, nenhuma credencial no codigo
```

Se a conexão cair ou nunca subir, `wifiKeepAlive()` (chamado todo `loop()`,
mas throttled a 1 tentativa a cada 10 s) chama `WiFi.disconnect()` +
`WiFi.begin()` de novo (mesma chamada sem argumentos), **para sempre, sem
desistir e sem abrir portal sozinho**. Isso é proposital (comentário no topo
do `main.cpp`): uma versão anterior abria o portal de configuração
automaticamente a cada falha e a placa ficava presa em modo AP, offline, sem
nunca mais reconectar.

O portal de configuração (`WiFiManager`, para trocar/cadastrar a rede sem
recompilar nem editar `secrets.h`) só abre por pedido explícito, de **dois**
jeitos:
- segurar o botão **BOOT** da placa por 5 segundos **durante a operação
  normal** (não no boot — GPIO0 baixo no reset entra em modo download e o
  app nem chega a rodar);
- com a **caixa fechada** (sem acesso ao BOOT): segurar **Push button 1 +
  Push button 2** juntos por 5 segundos. Qualquer combinação de botões serve
  desde que não inclua o Push button 11 (é o PTT do rádio — aperto frequente
  durante uso normal, não pode ser parte de um gesto "segurar 5s").

```cpp
// src/main.cpp — mesma função pros dois gestos
static void startWifiPortal() {
  wm.setConfigPortalBlocking(false);
  wm.startConfigPortal(AP_NAME);  // AP_NAME = "ButtonBox-Setup"
  portalAtivo = true;             // NAO usar o retorno — ver nota abaixo
}
```

**Bug corrigido (out/2026):** `startConfigPortal()` em modo não-bloqueante
sempre retorna `false` na hora (só entra no loop bloqueante se configurado
bloqueante, que não é o caso aqui). Atribuir esse retorno direto a
`portalAtivo` fazia o `loop()` nunca chamar `wm.process()` — o AP do portal
subia (SSID aparecia) mas a página de configuração nunca respondia, porque o
handler de DNS/HTTP só roda dentro de `wm.process()`. Agora `portalAtivo` é
setado para `true` incondicionalmente, e só volta a `false` quando
`wm.process()` retorna `true` (rede nova conectada com sucesso).

`WiFi.setSleep(false)` só é chamado dentro de `startOta()`, **depois** de
`WiFi.begin()` já ter sido chamado em `setup()` — chamar antes, com o rádio
ainda não inicializado em STA, impede o portal AP de subir (lição documentada
no topo do arquivo).

## 12. Como o OTA é iniciado

`ArduinoOTA` + `ESPmDNS`, inicializados uma única vez por `startOta()`,
chamado de `loop()` só quando há WiFi conectado:
```cpp
void loop() {
  if (WiFi.status() == WL_CONNECTED) startOta();
  if (otaReady) ArduinoOTA.handle();
  if (otaRunning) return;   // nada mais roda durante upload
  ...
}
```
`startOta()` é guardado por `otaReady` (só roda uma vez): registra hostname
(`OTA_HOSTNAME`, de `secrets.h`), callbacks de `onStart`/`onEnd`/`onError`, e
**propositalmente nenhum callback de `onProgress`** — escrever na CDC durante
o upload bloqueia quando o host não está lendo a porta, o que travava
`ArduinoOTA.handle()` e matava a transferência pela metade (era a causa do
antigo "Error Uploading" em ~29%, resolvida antes desta baseline).

Uma vez que o upload OTA começa (`otaRunning = true` no `onStart`), o
`loop()` retorna cedo logo depois de chamar `ArduinoOTA.handle()` — nenhuma
outra lógica (HID, serial, WiFi keep-alive) roda até o upload terminar.

## 13. Como o firmware é atualizado

Dois caminhos, ambos via o mesmo `platformio.ini`:

- **USB (cabo)**: `pio run -e esp32s3-supermini -t upload`. O
  `extra_scripts = pre:scripts/enter_bootloader.py` roda antes do upload:
  acha a porta da placa pelo MAC (`custom_expected_mac`), abre com
  `dtr=False, rts=False`, manda `BOOTLOADER\n` (o mesmo comando do item 10),
  espera até 10 s por uma nova porta em modo download, e reaponta
  `UPLOAD_PORT` para ela. **Não exige segurar o botão BOOT manualmente** —
  isso já era um problema resolvido antes desta baseline.
- **OTA (WiFi)**: `pio run -e esp32s3-ota -t upload` (env `[env:ota]`, que
  estende `esp32s3-supermini` com `upload_protocol = espota`). O
  `extra_scripts = pre:scripts/ota_port_by_mac.py` descobre o IP atual da
  placa pelo MAC (`arp -a` após um ping de broadcast) e substitui
  `UPLOAD_PORT` por ele — contorna o fato de o `espota` não resolver nomes
  `.local` (mDNS) e o IP poder mudar por DHCP.

Em ambos os casos, o binário sobe para a partição OTA ociosa (`ota_0`/`ota_1`,
1.25 MB cada, ver `default.csv`) e o bootloader alterna para ela no próximo
boot — não há necessidade de apagar a flash inteira.

## 14. Qual board/env do PlatformIO deve ser usado

- **Board**: `esp32-s3-fh4r2` (`boards/esp32-s3-fh4r2.json`, custom, **não** o
  `esp32-s3-devkitc-1` genérico) — 4 MB flash + 2 MB PSRAM quad
  (`memory_type=qio_qspi`), partições `default.csv`. Usar o devkit genérico
  (8 MB, sem esta PSRAM) causa **boot loop** nesta placa física (histórico,
  documentado em `HANDOFF.md`).
- **Env para desenvolvimento normal (compilar + gravar + rodar)**:
  `[env:esp32s3-supermini]` — o único com o firmware de produção
  (`src_filter = +<main.cpp>`), HID + CDC + WiFi + OTA completos.
- **Env `[env:diag]`**: firmware mínimo alternativo (`src/diag.cpp`,
  `ARDUINO_USB_MODE=1`, só imprime `"alive N"` a cada 500 ms). Existe só para
  isolar problemas de toolchain/board/gravação da lógica de HID — **não é o
  firmware do produto**, não expõe HID nenhum.
- **Env `[env:ota]`**: mesmo firmware de `esp32s3-supermini` (via `extends`),
  só troca o protocolo de upload para WiFi.

## 15. Quais arquivos são críticos e não devem ser alterados sem necessidade

| Arquivo | Por quê é crítico |
|---|---|
| `src/main.cpp` | Toda a lógica de HID, WiFi, OTA e console serial. Contém, em comentários no topo e ao redor do comando `BOOTLOADER`, o histórico de bugs já resolvidos (portal preso, `setSleep` antes do `begin`, escrita na CDC travando OTA, registrador RTC prendendo em bootloader) — remover esses comentários ou desfazer essas decisões reintroduz bugs já corrigidos. |
| `platformio.ini` | `board_build.extra_flags` com `ARDUINO_USB_MODE=0` é o que liga o HID (o board.json por padrão traz `MODE=1`, que **não faz HID**). `-DBOARD_HAS_PSRAM` é o que resolve o `Flash Read Failed` do OTA. `-DUSB_PRODUCT`/`-DUSB_MANUFACTURER` evitam o vazamento do nome do board.json pro descriptor USB. `upload_speed=115200` é proposital (velocidade alta falha o handshake do esptool sobre a CDC do TinyUSB). |
| `boards/esp32-s3-fh4r2.json` | Board definition customizada (4 MB flash + PSRAM); trocar por um board genérico já causou boot loop no passado. |
| `scripts/enter_bootloader.py` | Mecanismo que permite gravar por USB sem apertar o botão BOOT manualmente; depende do comando `BOOTLOADER` em `main.cpp` estar usando `usb_persist_restart()` (não o registrador RTC direto). |
| `scripts/ota_port_by_mac.py` | Mecanismo que permite o `espota` achar a placa sem IP fixo nem mDNS funcionando. |
| `include/secrets.h` | Só o hostname OTA (`OTA_HOSTNAME`) — WiFi não mora mais aqui, ver seção 11. Git-ignorado — nunca deve ser commitado nem ter seu conteúdo impresso/logado. |
| `~/.platformio/packages/framework-arduinoespressif32` (core instalado) | Não é deste projeto, mas o comportamento de USB/HID/CDC descrito aqui depende da versão instalada (`espressif32@6.12.0` / `framework-arduinoespressif32@3.20017.241212`, ver `docs/BASELINE.md`). Uma atualização do core pode mudar defaults (ex.: `USB_PID`, layout do report HID). |

Arquivo **não** crítico e livre para uso exploratório: `src/diag.cpp` (env de
diagnóstico isolado, não afeta o firmware de produção).

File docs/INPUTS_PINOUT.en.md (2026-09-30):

[🇧🇷 Português](INPUTS_PINOUT.md) | 🇺🇸 English

# INPUTS_PINOUT.md — Final hardware input architecture

> Pinout definition document — the **reasoning** behind each pin/channel
> choice. Based on the ESP32-S3 chip's real constraints (verified in
> `variants/esp32s3/pins_arduino.h` from the installed Arduino-ESP32
> core) and on the MCP23017 and 74HC4067 datasheet capabilities.
>
> **The numbers that actually apply live in `include/board_config.h`.**
> Switched boards or want a different pinout? Edit only that file — no
> other `.cpp`/`.h` in the project has a fixed pin/channel/address. This
> document still stands as an explanation of *why* each choice was made
> (electrical constraints, expansion headroom, etc.), not as the source
> of the current values.

## Why this distribution

> **Revision 2 (Sep 2026) — the pinout changed.** Revision 1 put the 8
> quadrature signals on direct GPIO and the five 74HC4067 control lines on
> GPIO 15, 16, 17, 18 and 21. On the **ESP32-S3 SuperMini** those five are
> not easily-accessible pins: they come out as pads on the underside of the
> module, beneath the board body, which makes hand soldering impractical.
> That applies to **every GPIO from 14 up** (14 itself included, not just
> 15 and above).
>
> **Decision (option B, chosen by the user):** the encoders move to the
> **MCP23017 port A** and the 74HC4067 takes over the button lines, using the
> header pins the encoders freed. Result: **no signal uses GPIO14 or above**,
> with GPIO 11, 12 and 13 still spare. Both ICs are the same as before — no
> new parts.

- **MCP23017 (I2C)**: carries the 8 **CLK/DT encoder signals** (port A) and,
  on port B, each **encoder's SW** plus the **4 toggle switches**. The SW
  lines are here for wiring reasons, not electrical ones: they leave the same
  KY-040 connector, so they follow their own encoder instead of crossing the
  enclosure to the mux.
- **74HC4067 (16-channel mux)**: carries the **11 push buttons**, **Start
  Engine**, the **2 ignition contacts** and the **parking brake
  microswitch** — 15 of the 16 channels. All mechanical contacts, which a
  polled scan serves with room to spare.
- **Direct ESP32-S3 GPIO**: only what *needs* a pin is left — I2C (8/9), the
  five mux control lines (4-7 and 10), WS2812 (1), the Start Engine LED (2)
  and BOOT (0).

### The price of this trade (read before touching the sampling)

Quadrature on GPIO had edge interrupts: **no transition is ever missed**, the
hardware wakes the MCU on each one. Over I2C there is no such thing —
transitions only show up if a sample lands between them.

A KY-040 has 20 detents per revolution and 4 Gray transitions per detent. At a
fast hand spin (~1.5 rev/s = 30 detents/s) a detent lasts ~33 ms and its 4
transitions sit ~5-10 ms apart. Sampling at **1 ms** catches them all with
margin. At 5 ms, two neighbouring transitions land in the same sample, the
quadrature state machine sees a 2-bit jump (impossible on a real contact),
treats it as noise and **drops the detent** — it never invents an event in the
wrong direction, but the click simply does not come out.

The main `loop()` ends with `delay(5)`, i.e. it would sample at 200 Hz. That
is why the MCP23017 read **left the loop** and became a **dedicated task**
(`lib/inputs/inputs.cpp`, core 0, priority above the loop), with its period in
`BOARD_MCP_SAMPLE_PERIOD_MS`. A 2-byte read at 400 kHz costs ~150 µs — about
15% of a bus that has no other device on it.

Once that task is up, **it owns I2C exclusively**: `inputs_update()`, in the
loop, only reads the cache it maintains. Do not call
`input_expander_update()` from anywhere else.

The **MCP23017 INT pin is not wired** (leave INTA/INTB unconnected — see
section 4 for why: an earlier revision reserved GPIO14 for it, and that pin
is precisely an underside pad on this board). If sampling ever becomes
event-driven, pick a free header GPIO at that time; do not reserve GPIO14
again.

- Both expanders keep some headroom (no free MCP pin, 1 free mux channel and
  3 free header GPIOs) for future expansion.

---

## 1. Input table

| INPUT | HARDWARE | PIN | TYPE | NOTES |
|---|---|---|---|---|
| Encoder 1 — CLK | MCP23017 | GPA0 | Digital, sampled at 1 kHz | Quadrature; decode CLK+DT together, no software debounce (debounce is inherent to the quadrature state machine). **Read through the RAW path** of `input_expander`, outside the 15 ms debounce. Output mapped as a fixed virtual +/- button — see section 8 |
| Encoder 1 — DT | MCP23017 | GPA1 | Digital, sampled at 1 kHz | See CLK note |
| Encoder 1 — SW | MCP23017 | GPB0 | Digital, polling | Encoder click; firmware debounce (15 ms) |
| Encoder 2 — CLK | MCP23017 | GPA2 | Digital, sampled at 1 kHz | Quadrature |
| Encoder 2 — DT | MCP23017 | GPA3 | Digital, sampled at 1 kHz | Quadrature |
| Encoder 2 — SW | MCP23017 | GPB1 | Digital, polling | Firmware debounce |
| Encoder 3 — CLK | MCP23017 | GPA4 | Digital, sampled at 1 kHz | Quadrature |
| Encoder 3 — DT | MCP23017 | GPA5 | Digital, sampled at 1 kHz | Quadrature |
| Encoder 3 — SW | MCP23017 | GPB2 | Digital, polling | Firmware debounce |
| Encoder 4 — CLK | MCP23017 | GPA6 | Digital, sampled at 1 kHz | Quadrature |
| Encoder 4 — DT | MCP23017 | GPA7 | Digital, sampled at 1 kHz | Quadrature |
| Encoder 4 — SW | MCP23017 | GPB3 | Digital, polling | Firmware debounce |
| Push button 1 | 74HC4067 | C0 | Digital, polling | ESP32 internal pull-up on the SIG line |
| Push button 2 | 74HC4067 | C1 | Digital, polling | idem |
| Push button 3 | 74HC4067 | C2 | Digital, polling | idem |
| Push button 4 | 74HC4067 | C3 | Digital, polling | idem |
| Push button 5 | 74HC4067 | C4 | Digital, polling | idem |
| Push button 6 | 74HC4067 | C5 | Digital, polling | idem |
| Push button 7 | 74HC4067 | C6 | Digital, polling | idem |
| Push button 8 | 74HC4067 | C7 | Digital, polling | idem |
| Push button 9 | 74HC4067 | C8 | Digital, polling | idem |
| Push button 10 | 74HC4067 | C9 | Digital, polling | idem |
| Push button 11 | 74HC4067 | C10 | Digital, polling | idem |
| Start Engine (push) | 74HC4067 | C11 | Digital, polling | A full 15-channel scan takes ~450 µs, spread over several `mux4067_scan()` calls — imperceptible for a button |
| Ignition — ON position | 74HC4067 | C12 | Digital, polling | Confirmed with the user: scooter key, 3 physical positions (1=OFF, 2=ON, 3=IGN/crank). The ON contact closes at position 2 and **stays closed** at position 3 (it does not open during cranking) |
| Ignition — IGN position | 74HC4067 | C13 | Digital, polling | **Momentary**: closed only while the key is held at position 3; the key is spring-returned and falls back to position 2 on release — this contact is not bistable, firmware must treat it as a pulse, not a state |
| Parking brake microswitch | 74HC4067 | C14 | Digital, polling | State (not pulse) — down=brake engaged, up=brake released. See mapping logic in section 7 |
| Toggle switch 1 (ON/OFF) | MCP23017 | GPB4 | Digital, polling | State, not urgent |
| Toggle switch 2 (ON/OFF) | MCP23017 | GPB5 | Digital, polling | State, not urgent |
| Toggle switch 3 (ON/OFF) | MCP23017 | GPB6 | Digital, polling | State, not urgent |
| Toggle switch 4 (ON/OFF) | MCP23017 | GPB7 | Digital, polling | State, not urgent |

Total: 31 physical signals (12 from the encoders + 11 push buttons + 1
microswitch + 2 ignition + 1 start + 4 toggle switches). 16 on the MCP23017
(full) and 15 on the 74HC4067 (1 channel free).

---

## 2. Full MCP23017 map (I2C)

| Pin | Use |
|---|---|
| GPA0 | Encoder 1 — CLK |
| GPA1 | Encoder 1 — DT |
| GPA2 | Encoder 2 — CLK |
| GPA3 | Encoder 2 — DT |
| GPA4 | Encoder 3 — CLK |
| GPA5 | Encoder 3 — DT |
| GPA6 | Encoder 4 — CLK |
| GPA7 | Encoder 4 — DT |
| GPB0 | Encoder 1 — SW |
| GPB1 | Encoder 2 — SW |
| GPB2 | Encoder 3 — SW |
| GPB3 | Encoder 4 — SW |
| GPB4 | Toggle switch 1 |
| GPB5 | Toggle switch 2 |
| GPB6 | Toggle switch 3 |
| GPB7 | Toggle switch 4 |

All 16 pins are taken. Future expansion goes through the free C15 mux
channel, the free GPIO 11/12/13, or a second MCP23017 on the same bus
(`0x21`, A0 to 3V3) — which costs no new pin at all.

**Port A is a quadrature path, not a button path.** The firmware reads
GPA0-GPA7 through the **raw** accessor (`input_expander_get_raw()`), outside
the layer's 15 ms debounce window — debouncing there would erase exactly the
transitions that make up a detent. Port B goes through debounce normally.

Configuration applied by `mcp23017_init()`: all 16 pins as inputs with the
internal pull-up (~100 kΩ) enabled, no polarity inversion (`IPOL = 0`, keeping
open=HIGH), `SEQOP` enabled so GPIOA+GPIOB come back in a single I2C
transaction, and `IOCON.MIRROR = 1` (INTA/INTB mirrored).

`MIRROR` is already on, but **INT is neither used nor wired**: sampling is
periodic (dedicated task, see "The price of this trade" at the top). Moving to
event-driven reads later would require enabling `GPINTEN` on the desired pins
with `INTCON = 0` (interrupt-on-change, not compare-against-`DEFVAL`), a new
wire from INTA to a free header GPIO, and an `attachInterrupt` on it. In other
words: **that is a hardware change**, not just firmware.

> Careful if you do: if a change happens between the GPIO read and the re-arm,
> INT can latch active and no new edge ever arrives. Whoever implements it must
> keep a safety poll in parallel. That race is precisely why periodic sampling
> was chosen first.

I2C address: 7 bits, `0x20`–`0x27` depending on the chip's A0/A1/A2
address pins (wire according to the board; with a single MCP, just tie
A0/A1/A2 to GND → address `0x20`).

---

## 3. Full 74HC4067 map (digital mux)

| Channel | Use |
|---|---|
| C0 | Push button 1 |
| C1 | Push button 2 |
| C2 | Push button 3 |
| C3 | Push button 4 |
| C4 | Push button 5 |
| C5 | Push button 6 |
| C6 | Push button 7 |
| C7 | Push button 8 |
| C8 | Push button 9 |
| C9 | Push button 10 |
| C10 | Push button 11 |
| C11 | Start Engine |
| C12 | Ignition — ON |
| C13 | Ignition — IGN |
| C14 | Parking brake microswitch |
| C15 | **Free** (future expansion) |

Control lines (not input channels, counted separately in the ESP32-S3 GPIO
budget — see section 4):

| Line | Function |
|---|---|
| S0 | Bit 0 of the channel address |
| S1 | Bit 1 of the channel address |
| S2 | Bit 2 of the channel address |
| S3 | Bit 3 of the channel address |
| SIG | Common output — the ESP32 reads the state of the currently selected channel here |

The 74HC4067 has no pull-up of its own (unlike the MCP23017), but the
firmware enables the ESP32's internal pull-up on the SIG line, which serves
every channel — no per-input resistor is needed. Details and the one
optional recommendation are in section 11.

---

### Ignition key logic (confirmed with the user)

Scooter-style key, 3 physical positions — **not** an ordinary 3-stable-
state rotary switch:

| Physical position | C12 (ON) | C13 (IGN) | Mechanical behavior |
|---|---|---|---|
| 1 — OFF | inactive | inactive | Stable — stays until the user moves it |
| 2 — ON | **active** | inactive | Stable — stays until the user moves it |
| 3 — IGN/start | **active** | **active** | **Momentary** — spring return; releases on its own and the key returns to position 2 as soon as the user lets go |

Consequences for the firmware (not implemented yet, only recorded here
for when the logic gets ported):
- C13 (IGN) must be treated as a **start pulse**, not a state — it never
  stays "latched" active on its own, always returns to 0 once the user's
  hand leaves the key.
- If the user moves the key directly from position 3 to position 1
  (skipping position 2), the firmware sees C12 and C13 drop practically
  together — the vehicle should be treated as OFF in that case, exactly
  as if it had passed through ON first.
- There's no valid combination of "IGN active with ON inactive" on this
  key — if that's ever read, it's a transient electrical transition
  (debounce), not a real state to report.

---

## 4. Direct ESP32-S3 GPIOs used

| GPIO | Function |
|---|---|
| GPIO0 | Board BOOT button — only the "hold 5 s to open the WiFi portal" gesture. Does not feed HID |
| GPIO1 | WS2812 — chain data (8x8 matrix + strip), see `docs/SYSTEM_INTEGRATION.md` |
| GPIO2 | Start Engine button LED (output, through 220 Ω) — lights with ignition ON, see section 6 |
| GPIO4 | 74HC4067 — S0 |
| GPIO5 | 74HC4067 — S1 |
| GPIO6 | 74HC4067 — S2 |
| GPIO7 | 74HC4067 — S3 |
| GPIO8 | I2C SDA (MCP23017) — Arduino-ESP32 core default (`pins_arduino.h`) |
| GPIO9 | I2C SCL (MCP23017) — core default |
| GPIO10 | 74HC4067 — SIG |

10 GPIOs used, **all within GPIO0-10**. No underside pad is required.

> **The MCP23017 INT is not wired.** An earlier version of this document
> reserved GPIO14 for it. That was doubly wrong: the firmware never enables
> `GPINTEN` nor attaches an interrupt (sampling is periodic, see "The price
> of this trade"), and **GPIO14 is also an underside pad** on this board —
> exactly what this revision exists to avoid. Leave the MCP23017 INTA and
> INTB unconnected.

Pins deliberately **avoided** in this allocation:
- **GPIO3, GPIO45, GPIO46** — ESP32-S3 strapping pins (affect boot mode / flash
  voltage); GPIO46 is also *input-only*.
- **GPIO19, GPIO20** — native USB (D-/D+), in use by HID/CDC. Never use as GPIO
  in this project.
- **GPIO14**, and **GPIO15-18, GPIO21 and everything from GPIO33 up** — they
  exist on the chip, but on the SuperMini they come out as underside pads.
  This is the constraint that drove this revision; do not go back to them
  without changing boards.
- **GPIO26-GPIO32** — internal bus to the in-package flash/PSRAM (SPI0/1). Not
  usable as GPIO on this board.
- **GPIO43, GPIO44** — UART0 TX/RX (default). Free in current use (the project
  uses native USB CDC, not UART0), but reserved for alternative serial
  debugging if ever needed.
- **GPIO48** — the board's built-in RGB LED (`PIN_NEOPIXEL` in the core).

---

## 5. GPIOs still free

| GPIO | Notes |
|---|---|
| GPIO11 | **Free on header** — first candidate for any new input/output |
| GPIO12 | **Free on header** |
| GPIO13 | **Free on header** |
| GPIO3 | Present on header, but it is a strapping pin — avoid without a reason |
| GPIO14-18, 21, 33-48 | Present on the chip; on the SuperMini they are underside pads. Treat as unavailable |

Three free header pins, plus mux channel C15, plus the option of a second
MCP23017 on the same I2C (16 inputs at zero pin cost). That comfortably covers
paddle shifters, an analog handbrake or a pedal set — bearing in mind that on
the HID side the bit budget is the real limit (section 9).

---

## 6. Outputs / actuators (outside the scope of inputs, recorded because it affects the GPIO budget)

### Start Engine button LED

Illuminated momentary button (chrome ring, red "ENGINE START" cap,
internal LED), a common model from Chinese sim racing sites, **3
terminals**: the LED and the switch share a common pin (COM), which is
part of both the switch circuit and the LED's cathode.

Identifying the 3 pins with a multimeter (before soldering):
1. Continuity mode, test the 3 pairs **with the button pressed** — the
   pair that closes only at that moment is COM + the switch pin.
2. Diode mode, test the remaining pairs without pressing — the pair that
   lights up faintly and shows ~1.8–2.2V (in one polarity) is the LED;
   red probe in this test = anode (+), black probe = cathode (COM).
3. The pin that shows up in both tests is the shared COM.

Wiring:

| Button terminal | Goes to | Note |
|---|---|---|
| COM (common, switch+LED) | GND | A single GND wire serves both circuits |
| Switch (NO) | 74HC4067 C11 | Already allocated in sections 1/3 — ESP32 internal pull-up on the SIG line, reads LOW when pressed |
| LED (anode, +) | ESP32-S3 **GPIO2**, through a **220 Ω** resistor (or 150 Ω for more brightness) | Dedicated digital output — lets the firmware decide when to light it up (always on, only with ignition in ON/IGN, blinking during cranking, etc.) instead of wiring it straight to a power rail |

Resistor calculated for the ESP32-S3 GPIO's 3.3V (don't use the 5V rail
directly on the GPIO): `R = (3.3V − Vf_LED) / I_desired`, with a typical
red LED `Vf` ≈ 2.0V and a target current of 6–9 mA → 220–150 Ω. Don't use
a resistor smaller than ~100 Ω, to avoid exceeding the ESP32-S3's safe
per-pin current.

GPIO2 comes off the "free" list (section 5) — reserved for this LED.

---

## 7. Mapping logic — parking brake (Euro Truck Simulator)

Behavior confirmed by the user: the lever is a **stable** 2-position
switch (not momentary like the ignition key) — **down = parking brake
engaged, up = brake released**.

Point of attention for when the firmware gets ported: Euro/American Truck
Simulator's default bind for the parking brake is a **toggle** (the key/
button flips the state on each press, it doesn't hold a level). A
physical 2-stable-position switch doesn't directly match that model — if
the firmware simply mirrored the switch's level onto the HID bit (low
level = bit held at 1, high level = bit held at 0), the game would
receive that as "holding the button down", which isn't what a toggle
expects.

**Decided with the user: option 1.** The firmware generates a pulse only
on the switch's state transition (it doesn't mirror the level):
- **up→down** edge: fires a single "toggle" pulse — assumes this engages
  the brake in the game;
- **down→up** edge: fires another single "toggle" pulse — assumes this
  releases the brake.

This keeps the lever's physical position always consistent with the
brake's state in the game, as long as the two start in sync (e.g., a
session always starts with the lever down / brake engaged, which matches
the real default of a parked truck).

**Implemented.** `updateTogglePulses()` in `src/main.cpp` — reuses the
same pulse mechanism as the encoders (30ms high + 20ms low gap). Before
this, the HID integration in section 10 treated `INPUT_HANDBRAKE` like any
other level button by oversight, which is exactly the wrong behavior
described above; fixed.

---

## 8. Mapping logic — encoders (decided: fixed virtual +/-)

**Decided with the user: the 4 KY-040 encoders always run in fixed
virtual +/- button mode, with no axis mode and no mode switching.** There
will be no toggle combo or mode-feedback LED — deliberately dropped as
not worth the extra complexity (4 LEDs, wiring, state-sync logic) for a
use case most simulation games don't use (almost every relevant bind —
cruise control, wipers, mirror, radio, etc. — accepts a discrete key/
button; very few accept an axis directly).

Behavior (not implemented yet, only specified):
- Each detent rotated **clockwise** generates a momentary pulse on a
  virtual "+" button (press and release).
- Each detent **counter-clockwise** generates a momentary pulse on a
  separate virtual "−" button.
- Therefore each encoder occupies **2 bits of the HID button bitmask**
  (one for +, one for −), plus the bit for its own SW (click), which is
  already mapped as a normal button on the 74HC4067 (section 1/3).
- No axis, no alternate mode, no mode-status LED — closed decision for
  this project.

---

## 9. HID bit budget (capacity check)

The firmware's current HID report descriptor (`docs/ARCHITECTURE.md`
item 7) **must not be altered** — it exposes a fixed 32-button bitmask
(`uint32_t buttons`). Check that everything decided so far fits within
that limit without touching the descriptor:

| Source | Bits |
|---|---|
| Push buttons 1–11 | 11 |
| SW of the 4 encoders (click) | 4 |
| Start Engine | 1 |
| Ignition — ON | 1 |
| Ignition — IGN | 1 |
| Toggle switches 1–4 | 4 |
| Parking brake (toggle pulse) | 1 |
| Encoders — virtual +/- button (4 × 2) | 8 |
| **Total used** | **31** |
| Free bits in the current HID | **1** |

Fits within the existing 32 bits, with no need to change the HID
descriptor — compatible with the "don't alter HID/USB descriptors"
constraint inherited from the earlier baseline. Only **1 free bit**
remains in the current descriptor.

**Expansion option confirmed by the user**: if the 32-bit budget turns
out to be insufficient in the future, the user already has a reference
profile/descriptor with **64 button slots** available to use as a base.
In other words, the 32-bit limit **isn't final** — it's just what the
current firmware uses; expanding to 64 buttons is a real, already
available option, whenever/if it's needed.

Important: this **is**, by definition, a change to the HID report
descriptor (the `USBHIDGamepad`'s `uint32_t buttons` would have to become
a larger bitmask — 64 bits, typically 2× `uint32_t` or a `uint8_t[8]` in
a custom report, since the Arduino-ESP32 core's `USBHIDGamepad` lib used
today is fixed at 32 buttons via `TUD_HID_REPORT_DESC_GAMEPAD`).
Therefore this change:
- **Isn't necessary now** — the current mapping fits within the existing
  32 bits.
- When it does happen, it's a deliberate, isolated firmware decision
  (swapping the report descriptor + the sending logic), not an
  incidental change — exactly the kind of change the baseline asks to be
  treated with caution, just now with the user's explicit authorization
  to make it **if and when** the 32nd bit ends up being insufficient.

---

## 10. HID integration — definitive INPUT LOGICAL ID → HID bit map

**Implemented.** The `lib/inputs` layer (INPUT_*) was integrated into the
main firmware (`src/main.cpp`), replacing the simulated/heartbeat values
with the real state of the 31 inputs. The HID report descriptor **was not
altered** (still `uint32_t buttons` via `USBHIDGamepad`, 32 bits, no
axes/hat used) — the 31 IDs fit exactly within the space already budgeted
in section 9 above.

Map rule: **bit = the numeric value of `InputId`** (0-30) — the enum is
already 0-based and sequential in `lib/inputs/inputs.h`, so there's no
separate indirection table to go stale. The full table (identical to the
comment at the top of `src/main.cpp`):

| INPUT LOGICAL ID | Bit | Button in joy.cpl | Type |
|---|---|---|---|
| INPUT_BUTTON_01..11 | 0-10 | 1-11 | level |
| INPUT_BUTTON_12 (encoder 1 SW) | 11 | 12 | level |
| INPUT_BUTTON_13 (encoder 2 SW) | 12 | 13 | level |
| INPUT_BUTTON_14 (encoder 3 SW) | 13 | 14 | level |
| INPUT_BUTTON_15 (encoder 4 SW) | 14 | 15 | level |
| INPUT_IGNITION_ON | 15 | 16 | pulse |
| INPUT_IGNITION_IGN | 16 | 17 | level |
| INPUT_START_ENGINE | 17 | 18 | level |
| INPUT_HANDBRAKE | 18 | 19 | pulse |
| INPUT_KILL_SWITCH_01..04 | 19-22 | 20-23 | pulse |
| INPUT_ENCODER_01_CW / _CCW | 23 / 24 | 24 / 25 | pulse |
| INPUT_ENCODER_02_CW / _CCW | 25 / 26 | 26 / 27 | pulse |
| INPUT_ENCODER_03_CW / _CCW | 27 / 28 | 28 / 29 | pulse |
| INPUT_ENCODER_04_CW / _CCW | 29 / 30 | 30 / 31 | pulse |
| **free** (was the bring-up heartbeat) | 31 | 32 | — |

**Level** inputs (buttons/`INPUT_IGNITION_IGN`/`INPUT_START_ENGINE`): the
already-debounced `inputs_get_state()` is mirrored directly onto the bit —
no extra logic in `main.cpp`. `INPUT_IGNITION_IGN` (the contact that only
closes while cranking) and `INPUT_START_ENGINE` (the separate illuminated
button) stay level because both are already physically momentary on their
own — the button releases itself, and the IGN contact, on a spring-
returning start switch (typical of a scooter-style key), also only stays
closed while held. A brief press/turn already produces the edge a game
toggle bind expects, no conversion needed.

Intended use (decided with the user):
- **`INPUT_IGNITION_IGN` (Button 17)**: the actual engine start — ETS2/
  ATS's "Engine startup/shutdown" bind. It's the key itself being turned
  further, just like a real car/truck (ON turns on the electrics, turning
  further cranks the starter).
- **`INPUT_START_ENGINE` (Button 18)**: a **separate illuminated button**,
  with no fixed destination — free for any purpose (starting the engine
  in a different racing game that has its own dedicated button, or
  whatever else needs a spare push button).

`INPUT_IGNITION_ON` (key position 2) is **pulse**, not level — the game
has a native bind for it, "Toggle Engine Electricity" (turns on the
dashboard/GPS without cranking the engine), confirmed as a *toggle* from
ETS2/ATS's own Controls menu. The physical switch holds its position, so
it has the same problem as the parking brake below. This only affects the
HID bit that goes to the game — `updateStartEngineLed()` reads
`inputs_get_state(INPUT_IGNITION_ON)` directly (not the HID bit), so the
Start Engine LED keeps following the key's physical position normally,
with no side effect from this conversion.

The 4 kill switches (`INPUT_KILL_SWITCH_01..04`) are also **pulse**, not
level — same reason: nearly every truck accessory in ETS2/ATS (hazard
lights, beacon light, cabin light, differential lock, etc.) is a *toggle*
bind in the game, and the switch style used here (bat/lever, holds its
position) is exactly meant for that. `INPUT_IGNITION_ON` and the 4 kill
switches share the same configurable `TOGGLE_PULSE_IDS` list, along with
the parking brake, in `src/main.cpp` — if one ends up bound to a
*hold*-type action instead (effect only exists while held, e.g. a horn),
just remove its `InputId` from the list to go back to level.

**Encoder** inputs (CW/CCW): since `lib/inputs` only exposes an EVENT for
rotation (never a "held level"), `main.cpp` translates each pending event
into a **momentary pulse** on the bit: it rises for 30ms, falls and stays
LOW for at least 20ms before the next pulse can start
(`updateEncoderPulses()`). This guarantees a rising AND a falling edge
visible to the host even with several detents in quick succession — the
game/SimHub always sees "press and release" an exact number of times,
never a "stuck" button.

**Parking brake** input (`INPUT_HANDBRAKE`): also a **pulse**, not a
level — same mechanic as the encoders (an event becomes a momentary
edge), but for a different GAME reason: Euro/American Truck Simulator's
default parking-brake bind is a toggle, and a 2-stable-position switch
doesn't match "hold a level" — see section 7 for the full reasoning.
`updateTogglePulses()` (the `TOGGLE_PULSE_IDS` list, shared with the 4
kill switches above) fires one pulse on each position change, in either
direction.

**BOOT no longer feeds the HID.** The old `BOOT -> bit 0 (Button 1)` was
a bring-up simulated value (pre-real-hardware); it was removed and bit 0
is now the real `INPUT_BUTTON_01`, coming from the MCP23017. The board's
physical BOOT button still exists only for the gesture that opens the
WiFi portal (hold for 5s) — that's WiFi logic, untouched.

**Heartbeat (bit 31 / Button 32): REMOVED.** It existed only to prove the HID
was alive while the hardware was not assembled. It went away once the 31 real
controls started responding — a button that fires by itself every second is
exactly what a game or SimHub binds by mistake during auto-learn. Bit 31 is now
**free** and is the first slot available for a new control (the descriptor still
declares 32 buttons).

### What's left to close this stage's success criterion

Test on `joy.cpl`, with the hardware physically assembled:
- each of the 31 buttons individually;
- multiple simultaneous buttons (no "ghosting" — there shouldn't be any,
  since there's no matrix, but worth confirming);
- the 4 encoders, CW and CCW direction for each;
- the 4 toggle switches, the ignition (3 positions), and the parking
  brake;
- the Start Engine button;
- confirm the HID keeps responding normally with the computer without
  SimHub open (the firmware doesn't depend on it — SimHub just consumes
  the HID that Windows already exposes).

---

## 11. Wiring / soldering diagram — GND or VCC?

**General rule: every button/switch has one terminal on the input pin/channel
and the other terminal on GND. Never on VCC.** The logic is *active-low*: at
rest the pin reads `HIGH` (pulled up by a pull-up), and when the contact
closes it's pulled to GND and reads `LOW`. Everything runs at 3.3 V. What
differs between subsystems is *who provides the pull-up* — and in most cases
**you don't solder any resistor at all**, because the firmware enables
internal pull-ups.

> **Correction (2026-09-24).** An earlier version of this document (and a
> comment in `lib/mux4067`) said **each** 74HC4067 input needed an external
> 10 kΩ resistor. That was overstated: the firmware already enables the
> ESP32's internal pull-up on the SIG line (`lib/mux4067/mux4067.cpp`,
> `pinMode(g_sig, INPUT_PULLUP)`), and the mux connects the selected channel
> to SIG, so that one pull-up already serves every channel. No per-input
> resistor is needed.

### Power and control connections (what usually makes "nothing work")

| Chip | Pin | Goes to | Notes |
|---|---|---|---|
| ESP32-S3 | 3V3 / GND | 3.3 V rail / common GND | everything referenced to the same GND |
| MCP23017 | VDD / VSS | 3.3 V / GND | |
| MCP23017 | **RESET** | **3.3 V** | do not leave floating — the chip can sit stuck in reset. Some breakouts already handle this; check yours |
| MCP23017 | A0, A1, A2 | **GND** | I2C address `0x20` (what `board_config.h` expects) |
| MCP23017 | SDA / SCL | GPIO8 / GPIO9 | need I2C pull-ups (~4.7 kΩ → 3.3 V). Breakouts usually have them; a bare chip does not. **With quadrature now riding on I2C, a marginal bus stops being "a button glitches sometimes" and becomes a dropped detent** — if in doubt, fit the 4.7 kΩ |
| MCP23017 | INTA and INTB | **leave unconnected** | the firmware does not use the expander's interrupt; sampling is periodic. On many breakouts (the CJMCU-2317 included) those outputs do not even reach the header |
| 74HC4067 | VCC / GND | 3.3 V / GND | |
| 74HC4067 | **EN (/E)** | **GND** | active low: at `HIGH` (or floating) it disables every channel. Some boards already ground it; check yours |
| 74HC4067 | S0 / S1 / S2 / S3 | GPIO4 / GPIO5 / GPIO6 / GPIO7 | per `include/board_config.h` |
| 74HC4067 | SIG | GPIO10 | idem |
| KY-040 | `+` | **3.3 V (not 5 V)** | the module's pull-up hangs off this pin; at 5 V it would inject 5 V into the MCP23017 inputs |

> **Wire length matters more than before.** The 8 CLK/DT lines now land on the
> MCP23017, and SDA/SCL carries the quadrature. Keep the MCP23017 close to the
> ESP32 (short I2C) and run the long wires to the encoders, not to the bus.

### ⚠️ 74HC4067 EN pin — must be wired to GND

The 74HC4067 has an **EN** pin (also labelled `/E` or `~E`, active LOW).
When EN is `HIGH` — including floating with no connection — the chip
**disables every channel at once**: SIG disconnects from all inputs, floats
HIGH through the ESP32 pull-up, and the firmware reads "no button pressed"
(or chaotic intermittent behaviour if the pin drifts).

**EN goes directly to GND.** No GPIO, no resistor — just a short wire from
EN to the GND rail. Without it, any noise on that pin kills the whole chip
and looks exactly like a bad contact on the buttons or on S0–S3.

> Some 74HC4067 breakout boards already ground EN internally — check your
> board's schematic before soldering. If it doesn't, add the wire.

---

### Push buttons 1–11, Start Engine, Ignition, parking brake (74HC4067)

Bare switches (two terminals). The firmware enables the ESP32 internal pull-up
on the SIG line (`pinMode(SIG, INPUT_PULLUP)`), and the mux connects the
selected channel to SIG — **that single pull-up serves every channel**. No
per-input resistor.

```
74HC4067 channel Cx ──→  Switch terminal 1
                         Switch terminal 2 ──→  GND
```

| Channel | What to wire |
|---|---|
| C0–C10 | Push buttons 1 to 11 |
| C11 | Start Engine (switch NO terminal; COM goes to GND) |
| C12 | Ignition — ON contact |
| C13 | Ignition — IGN contact (crank) |
| C14 | Parking brake microswitch |
| C15 | free |

Logic: the channel reads `HIGH` at rest → `LOW` when closed to GND.

**Optional, only if `mux-test` shows unstable readings** (more likely with long
wires): **a single** 10 kΩ resistor between the **SIG line (GPIO10)** and
3.3 V. Since SIG is common to every channel, that one resistor serves all
fifteen. *This is an expectation from circuit physics; it has not been measured
on assembled hardware — test without it, and only add it if you need it.*

**Parking brake:** the firmware treats "contact closed to GND" as engaged.
Which lever position closes the contact depends on whether you use the
microswitch NO or NC terminal; if it ends up inverted, swap the terminal.

### Ignition (3 positions, scooter key switch) — 74HC4067

```
COM (common)            ──→  GND
ON contact              ──→  74HC4067 C12
IGN contact (crank)     ──→  74HC4067 C13
```

Before wiring, confirm with a multimeter that the ON contact stays closed at
position 3 (crank) — see section 3.

### Start Engine button (3 terminals) and its LED

```
COM            ──→  GND               (serves both the switch and the LED)
Switch (NO)    ──→  74HC4067 C11
LED anode (+)  ──→  220 Ω ──→  ESP32-S3 GPIO2
```

Resistor for 3.3 V: `R = (3.3 V − Vf) / I` with `Vf ≈ 2.0 V` (red LED) and
`I ≈ 6–9 mA` → 220–150 Ω. Recommended minimum: 100 Ω.

**Implemented behavior** (`updateStartEngineLed()` in `src/main.cpp`): the LED
mirrors the **ignition**, not the button.

| Key position | LED |
|---|---|
| 1 — OFF | off |
| 2 — ON | **on** |
| 3 — IGN/crank | **on** (the ON contact does not open while cranking — section 3) |

So it says "ignition is on, the start button is available", just like a real
car. Pressing Start Engine itself does not change the LED.

> GPIO2 is configured as an output in `setup()` and starts LOW. Before that it
> sat as a floating input, and the LED would glow faintly or flicker on its own
> — if you saw that on an earlier firmware, that was the cause, not a solder
> defect.

### KY-040 encoders — CLK, DT and SW, all on the MCP23017

The MCP23017 has an internal pull-up (~100 kΩ) on all 16 pins, and the KY-040
module already carries its own on the PCB. No resistor to solder.

```
KY-040 #1   CLK ──→ GPA0    DT ──→ GPA1    SW ──→ GPB0
KY-040 #2   CLK ──→ GPA2    DT ──→ GPA3    SW ──→ GPB1
KY-040 #3   CLK ──→ GPA4    DT ──→ GPA5    SW ──→ GPB2
KY-040 #4   CLK ──→ GPA6    DT ──→ GPA7    SW ──→ GPB3
all         GND ──→ GND     +  ──→ 3.3 V
```

Check your module with a multimeter (between `SW` and `+` should read ~10 kΩ);
some clones lack the `SW` pull-up — the MCP23017 internal one covers that case.

> **If one physical detent does not produce exactly one event**, suspect number
> one is now the sampling period (`BOARD_MCP_SAMPLE_PERIOD_MS`) or a marginal
> I2C bus — not the decoder. Run the isolated `encoder-test` before touching the
> quadrature state machine, which did not change at all in this revision.

### Toggle switches 1–4 — MCP23017

```
Toggle switch 1 ──→ GPB4      Toggle switch 3 ──→ GPB6
Toggle switch 2 ──→ GPB5      Toggle switch 4 ──→ GPB7
the other terminal of each ──→ GND
```

### WS2812 matrix + strip

**External 5 V** supply straight to the matrix/strip (~4.4 A peak with 74 LEDs
at full white — the ESP32 USB rail cannot take it), **common GND** with the
ESP32, data `GPIO1 → matrix DIN → matrix DOUT → strip DIN`. Recommended: a
~1000 µF capacitor between +5 V and GND near the first LED and a ~330–470 Ω
series resistor on the data wire.

### Quick-reference table

| Component | Terminal 1 goes to | Terminal 2 goes to | Pull-up |
|---|---|---|---|
| Push buttons 1–11 | 74HC4067 C0–C10 | **GND** | ESP32 internal, on the SIG line |
| Start Engine (switch) | 74HC4067 C11 | **GND** (via COM) | ESP32 internal, on the SIG line |
| Ignition — ON / IGN | 74HC4067 C12 / C13 | **GND** (via COM) | ESP32 internal, on the SIG line |
| Parking brake | 74HC4067 C14 | **GND** | ESP32 internal, on the SIG line |
| KY-040 CLK / DT | MCP23017 GPA0–GPA7 | KY-040 module (GND / `+`) | KY-040 PCB + MCP internal |
| Encoder SW | MCP23017 GPB0–GPB3 | KY-040 module (GND / `+`) | KY-040 PCB + MCP internal |
| Toggle switches 1–4 | MCP23017 GPB4–GPB7 | **GND** | MCP internal (~100 kΩ) |
| Start Engine (LED) | GPIO2 through 220 Ω | **GND** (via COM) | — (output; HIGH lights it, follows the ignition) |

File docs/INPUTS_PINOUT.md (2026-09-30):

🇧🇷 Português | [🇺🇸 English](INPUTS_PINOUT.en.md)

# INPUTS_PINOUT.md — Arquitetura de entradas do hardware final

> Documento de definição de pinout — o **raciocínio** por trás de cada
> escolha de pino/canal. Baseado nas restrições reais do chip ESP32-S3
> (verificadas em `variants/esp32s3/pins_arduino.h` do core Arduino-ESP32
> instalado) e nas capacidades de datasheet do MCP23017 e do 74HC4067.
>
> **Os números que valem de verdade estão em `include/board_config.h`.**
> Trocou de placa ou quer outro pinout? Edite só aquele arquivo — nenhum
> outro `.cpp`/`.h` do projeto tem pino/canal/endereço fixo. Este documento
> continua valendo como explicação de *por que* cada escolha foi feita
> (restrições elétricas, folga de expansão etc.), não como fonte dos
> valores atuais.

## Por que esta distribuição

> **Revisão 2 (set/2026) — o pinout mudou.** A revisão 1 punha os 8 sinais
> de quadratura em GPIO direto e as 5 linhas do 74HC4067 nos GPIO 15, 16,
> 17, 18 e 21. Na **ESP32-S3 SuperMini** esses cinco não existem como pino
> de fácil acesso: saem em pads na face inferior do módulo, sob o corpo da
> placa, o que torna a solda manual impraticável. Isso vale para **todo
> GPIO a partir do 14** (o próprio 14 incluído, não só 15 pra cima).
>
> **Decisão (opção B, escolhida pelo usuário):** os encoders migram para o
> **banco A do MCP23017** e o 74HC4067 assume as linhas de botão, ocupando
> os pinos de header que os encoders liberaram. Resultado: **nenhum sinal
> usa GPIO14 ou acima**, e ainda sobram GPIO 11, 12 e 13 livres. Os dois CIs
> são os mesmos de antes — nenhuma peça nova.

- **MCP23017 (I2C)**: leva os 8 sinais **CLK/DT dos 4 encoders** (banco A) e,
  no banco B, o **SW de cada encoder** + as **4 chaves tipo caça**. Os SW
  ficam aqui por fiação, não por eletrônica: saem do mesmo conector do
  KY-040, então acompanham o CLK/DT do próprio encoder em vez de atravessar
  a caixa até o mux.
- **74HC4067 (mux de 16 canais)**: leva os **11 push buttons**, o **Start
  Engine**, os **2 contatos da ignição** e o **microswitch do freio de
  estacionamento** — 15 dos 16 canais. Todas entradas de contato mecânico,
  que o scan por polling atende de sobra.
- **GPIO direto do ESP32-S3**: sobra só o que *precisa* de pino — I2C (8/9),
  as 5 linhas de controle do mux (4-7 e 10), WS2812 (1), LED do Start
  Engine (2) e BOOT (0).

### O preço dessa troca (leia antes de mexer na amostragem)

Quadratura em GPIO tinha interrupção por borda: **nenhuma transição se
perde**, o hardware acorda a MCU em cada uma. Por I2C não existe isso — as
transições só aparecem se a amostragem cair entre elas.

Um KY-040 tem 20 detents por volta e 4 transições de Gray por detent. Num
giro rápido de mão (~1,5 volta/s = 30 detents/s), um detent dura ~33 ms e
suas 4 transições ficam ~5-10 ms uma da outra. Amostrando a **1 ms**, todas
são vistas com folga. Amostrando a 5 ms, duas transições vizinhas caem na
mesma amostra, a máquina de quadratura vê um salto de 2 bits (impossível num
contato real), trata como ruído e **perde o detent** — ela nunca inventa um
evento no sentido errado, mas o clique simplesmente não sai.

O `loop()` principal termina com `delay(5)`, ou seja, amostraria a 200 Hz.
Por isso a leitura do MCP23017 **saiu do loop** e virou uma **task dedicada**
(`lib/inputs/inputs.cpp`, core 0, prioridade acima do loop), com período em
`BOARD_MCP_SAMPLE_PERIOD_MS`. Uma leitura de 2 bytes a 400 kHz custa ~150 µs
— ~15% de um barramento que não tem mais nenhum outro dispositivo.

Depois que essa task sobe, **ela é a única dona do I2C**: `inputs_update()`,
no loop, só lê o cache que ela mantém. Não chame `input_expander_update()`
de nenhum outro lugar.

O pino **INT do MCP23017 não é fiado** (deixe INTA/INTB sem conexão — ver
seção 4 para o porquê: uma revisão anterior reservava o GPIO14 para ele, e
esse pino é justamente um pad da face inferior nesta placa). Se um dia a
amostragem virar orientada a evento, escolha então um GPIO de header livre
na época; não volte a reservar o GPIO14.

- Ambos os expansores ficam com folga (nenhum canal livre no MCP, 1 canal
  livre no mux, e 3 GPIO de header livres) para expansão futura.

---

## 1. Tabela de entradas

| ENTRADA | HARDWARE | PINO | TIPO | OBSERVAÇÃO |
|---|---|---|---|---|
| Encoder 1 — CLK | MCP23017 | GPA0 | Digital, amostrado 1 kHz | Quadratura; decodificar CLK+DT juntos, sem debounce por software (debounce é inerente à máquina de estados de quadratura). **Lido pelo caminho CRU** do `input_expander`, fora do debounce de 15 ms. Saída mapeada como botão virtual +/- fixo — ver seção 8 |
| Encoder 1 — DT | MCP23017 | GPA1 | Digital, amostrado 1 kHz | Ver observação do CLK |
| Encoder 1 — SW | MCP23017 | GPB0 | Digital, polling | Clique do encoder; debounce por firmware (15 ms) |
| Encoder 2 — CLK | MCP23017 | GPA2 | Digital, amostrado 1 kHz | Quadratura |
| Encoder 2 — DT | MCP23017 | GPA3 | Digital, amostrado 1 kHz | Quadratura |
| Encoder 2 — SW | MCP23017 | GPB1 | Digital, polling | Debounce por firmware |
| Encoder 3 — CLK | MCP23017 | GPA4 | Digital, amostrado 1 kHz | Quadratura |
| Encoder 3 — DT | MCP23017 | GPA5 | Digital, amostrado 1 kHz | Quadratura |
| Encoder 3 — SW | MCP23017 | GPB2 | Digital, polling | Debounce por firmware |
| Encoder 4 — CLK | MCP23017 | GPA6 | Digital, amostrado 1 kHz | Quadratura |
| Encoder 4 — DT | MCP23017 | GPA7 | Digital, amostrado 1 kHz | Quadratura |
| Encoder 4 — SW | MCP23017 | GPB3 | Digital, polling | Debounce por firmware |
| Push button 1 | 74HC4067 | C0 | Digital, polling | Pull-up interno da ESP32 na linha SIG |
| Push button 2 | 74HC4067 | C1 | Digital, polling | idem |
| Push button 3 | 74HC4067 | C2 | Digital, polling | idem |
| Push button 4 | 74HC4067 | C3 | Digital, polling | idem |
| Push button 5 | 74HC4067 | C4 | Digital, polling | idem |
| Push button 6 | 74HC4067 | C5 | Digital, polling | idem |
| Push button 7 | 74HC4067 | C6 | Digital, polling | idem |
| Push button 8 | 74HC4067 | C7 | Digital, polling | idem |
| Push button 9 | 74HC4067 | C8 | Digital, polling | idem |
| Push button 10 | 74HC4067 | C9 | Digital, polling | idem |
| Push button 11 | 74HC4067 | C10 | Digital, polling | idem |
| Start Engine (push) | 74HC4067 | C11 | Digital, polling | Um ciclo completo de scan dos 15 canais leva ~450 µs, repartido em várias chamadas de `mux4067_scan()` — imperceptível para um botão |
| Ignição — posição ON | 74HC4067 | C12 | Digital, polling | Confirmado pelo usuário: chave de scooter, 3 posições físicas (1=OFF, 2=ON, 3=IGN/partida). Contato ON fecha na posição 2 e **continua fechado** na posição 3 (não abre durante a partida) |
| Ignição — posição IGN | 74HC4067 | C13 | Digital, polling | **Momentâneo**: só fecha enquanto a chave é segurada na posição 3; a chave tem retorno por mola e volta sozinha para a posição 2 ao ser solta — este contato não é biestável, o firmware deve tratá-lo como pulso, não como estado |
| Microswitch freio de estacionamento | 74HC4067 | C14 | Digital, polling | Estado (não pulso) — down=freio acionado, up=freio liberado. Ver lógica de mapeamento na seção 7 |
| Chave caça 1 (ON/OFF) | MCP23017 | GPB4 | Digital, polling | Estado, sem urgência |
| Chave caça 2 (ON/OFF) | MCP23017 | GPB5 | Digital, polling | Estado, sem urgência |
| Chave caça 3 (ON/OFF) | MCP23017 | GPB6 | Digital, polling | Estado, sem urgência |
| Chave caça 4 (ON/OFF) | MCP23017 | GPB7 | Digital, polling | Estado, sem urgência |

Total: 31 sinais físicos (12 dos encoders + 11 push buttons + 1 microswitch +
2 da ignição + 1 start + 4 chaves caça). 16 no MCP23017 (lotado) e 15 no
74HC4067 (1 canal livre).

---

## 2. Mapa completo do MCP23017 (I2C)

| Pino | Uso |
|---|---|
| GPA0 | Encoder 1 — CLK |
| GPA1 | Encoder 1 — DT |
| GPA2 | Encoder 2 — CLK |
| GPA3 | Encoder 2 — DT |
| GPA4 | Encoder 3 — CLK |
| GPA5 | Encoder 3 — DT |
| GPA6 | Encoder 4 — CLK |
| GPA7 | Encoder 4 — DT |
| GPB0 | Encoder 1 — SW |
| GPB1 | Encoder 2 — SW |
| GPB2 | Encoder 3 — SW |
| GPB3 | Encoder 4 — SW |
| GPB4 | Chave caça 1 |
| GPB5 | Chave caça 2 |
| GPB6 | Chave caça 3 |
| GPB7 | Chave caça 4 |

Os 16 pinos estão ocupados. Expansão futura entra pelo canal C15 livre do
mux, pelos GPIO 11/12/13 livres, ou por um segundo MCP23017 no mesmo
barramento (`0x21`, com A0 em 3V3) — que não custa nenhum pino novo.

**Banco A é caminho de quadratura, não de botão.** O firmware lê GPA0-GPA7
pelo acessor **cru** (`input_expander_get_raw()`), fora da janela de debounce
de 15 ms da camada — aplicar debounce ali apagaria justamente as transições
que formam o detent. O banco B passa normalmente pelo debounce.

Configuração aplicada por `mcp23017_init()`: os 16 pinos como entrada, com
pull-up interno (~100 kΩ) ligado em todos, sem inversão de polaridade
(`IPOL = 0`, mantendo aberto=HIGH), `SEQOP` habilitado para ler GPIOA+GPIOB
numa única transação I2C e `IOCON.MIRROR = 1` (INTA/INTB espelhados).

O `MIRROR` já está ligado, mas o **INT não é usado nem fiado**: a amostragem
é periódica (task dedicada, ver a seção "O preço dessa troca" no topo).
Migrar para leitura orientada a evento no futuro exigiria habilitar
`GPINTEN` nos pinos desejados com `INTCON = 0` (interrupção por mudança de
estado, não por comparação com `DEFVAL`), um fio novo do INTA até um GPIO de
header livre e um `attachInterrupt` nele. Ou seja: **é mudança de hardware**,
não só de firmware.

> Cuidado ao fazer isso: se uma mudança acontecer entre a leitura de GPIO e
> o rearme, o INT pode ficar travado em nível ativo e nenhuma borda nova
> aparece. Quem for implementar precisa manter um polling de segurança em
> paralelo. É justamente por essa corrida que a amostragem periódica foi
> escolhida primeiro.

Endereço I2C: 7 bits, `0x20`–`0x27` conforme os pinos de endereço A0/A1/A2 do
chip (a fiar conforme a placa; com um único MCP basta amarrar A0/A1/A2 no GND
→ endereço `0x20`).

---

## 3. Mapa completo do 74HC4067 (mux digital)

| Canal | Uso |
|---|---|
| C0 | Push button 1 |
| C1 | Push button 2 |
| C2 | Push button 3 |
| C3 | Push button 4 |
| C4 | Push button 5 |
| C5 | Push button 6 |
| C6 | Push button 7 |
| C7 | Push button 8 |
| C8 | Push button 9 |
| C9 | Push button 10 |
| C10 | Push button 11 |
| C11 | Start Engine |
| C12 | Ignição — ON |
| C13 | Ignição — IGN |
| C14 | Microswitch freio de estacionamento |
| C15 | **Livre** (expansão futura) |

Linhas de controle (não são canais de entrada, contam à parte no orçamento de
GPIO do ESP32-S3 — ver seção 4):

| Linha | Função |
|---|---|
| S0 | Bit 0 do endereço do canal |
| S1 | Bit 1 do endereço do canal |
| S2 | Bit 2 do endereço do canal |
| S3 | Bit 3 do endereço do canal |
| SIG | Saída comum — a ESP32 lê aqui o estado do canal atualmente selecionado |

O 74HC4067 não tem pull-up próprio (ao contrário do MCP23017), mas o
firmware liga o pull-up interno da ESP32 na linha SIG, que serve todos os
canais — nenhum resistor por entrada é necessário. Detalhes e a única
recomendação opcional na seção 11.

---

### Lógica da chave de ignição (confirmada com o usuário)

Chave de scooter, 3 posições físicas, **não** é uma chave rotativa comum de
3 estados estáveis:

| Posição física | C12 (ON) | C13 (IGN) | Comportamento mecânico |
|---|---|---|---|
| 1 — OFF | inativo | inativo | Estável — permanece até o usuário mover |
| 2 — ON | **ativo** | inativo | Estável — permanece até o usuário mover |
| 3 — IGN/partida | **ativo** | **ativo** | **Momentâneo** — retorno por mola; some sozinho e a chave volta para a posição 2 assim que o usuário solta |

Consequências para o firmware (ainda não implementado, só registrado aqui
para quando for portar a lógica):
- C13 (IGN) deve ser tratado como **pulso de partida**, não como estado —
  nunca fica "travado" ativo sozinho, sempre retorna a 0 quando a mão do
  usuário sai da chave.
- Se o usuário mover a chave direto da posição 3 para a posição 1 (pulando a
  posição 2), o firmware vê C12 e C13 caindo praticamente juntos — o
  veículo deve ser tratado como desligado (OFF) nesse caso, exatamente como
  se tivesse passado por ON primeiro.
- Não existe uma combinação válida de "IGN ativo com ON inativo" nesta
  chave — se isso for lido, é transição elétrica passageira (debounce), não
  um estado real a ser reportado.

---

## 4. GPIOs diretos do ESP32-S3 usados

| GPIO | Função |
|---|---|
| GPIO0 | Botão BOOT da placa — só o gesto de abrir o portal de WiFi (segurar 5 s). Não alimenta HID |
| GPIO1 | WS2812 — dado da cadeia (matriz 8x8 + fita), ver `docs/SYSTEM_INTEGRATION.md` |
| GPIO2 | LED do botão Start Engine (saída, via 220 Ω) — acende com a ignição em ON, ver seção 6 |
| GPIO4 | 74HC4067 — S0 |
| GPIO5 | 74HC4067 — S1 |
| GPIO6 | 74HC4067 — S2 |
| GPIO7 | 74HC4067 — S3 |
| GPIO8 | I2C SDA (MCP23017) — pino default do core Arduino-ESP32 (`pins_arduino.h`) |
| GPIO9 | I2C SCL (MCP23017) — pino default do core |
| GPIO10 | 74HC4067 — SIG |

10 GPIOs usados, **todos na faixa GPIO0-10**. Nenhum pad da face inferior é
necessário.

> **O INT do MCP23017 não é fiado.** Uma versão anterior deste documento
> reservava o GPIO14 para ele. Era erro duplo: o firmware nunca habilita
> `GPINTEN` nem registra `attachInterrupt` (a amostragem é periódica, seção
> "O preço dessa troca"), e o **GPIO14 também é pad da face inferior** nesta
> placa — justamente o que esta revisão existe para evitar. Deixe INTA e
> INTB do MCP23017 sem conexão.

Pinos deliberadamente **evitados** nesta alocação:
- **GPIO3, GPIO45, GPIO46** — strapping pins do ESP32-S3 (afetam modo de
  boot/tensão da flash); GPIO46 além disso é *input-only*.
- **GPIO19, GPIO20** — USB nativo (D-/D+), em uso pelo HID/CDC. Nunca usar
  como GPIO neste projeto.
- **GPIO14** e **GPIO15-18, GPIO21 e tudo de GPIO33 pra cima** — existem no
  chip, mas na SuperMini saem em pads na face inferior. É a restrição que
  motivou esta revisão; não voltar a usá-los sem trocar de placa.
- **GPIO26-GPIO32** — barramento interno para a flash/PSRAM em pacote
  (SPI0/1). Não existem como GPIO utilizável nesta placa.
- **GPIO43, GPIO44** — UART0 TX/RX (default). Livres no uso atual (o projeto
  usa USB CDC nativo, não UART0), mas reservados para depuração serial
  alternativa se um dia for necessário.
- **GPIO48** — LED RGB (NeoPixel) embutido da placa (`PIN_NEOPIXEL` no core).

---

## 5. GPIOs ainda livres

| GPIO | Observação |
|---|---|
| GPIO11 | **Livre em header** — primeiro candidato para qualquer entrada/saída nova |
| GPIO12 | **Livre em header** |
| GPIO13 | **Livre em header** |
| GPIO3 | Existe em header, mas é strapping — evitar até ter motivo |
| GPIO14-18, 21, 33-48 | Existem no chip; na SuperMini são pads da face inferior. Tratar como indisponíveis |

Três pinos de header livres, mais o canal C15 do mux, mais a possibilidade
de um segundo MCP23017 no mesmo I2C (16 entradas a custo zero de pino). Isso
cobre com folga paddle shifters, freio de mão analógico ou pedaleira —
lembrando que, do lado do HID, o orçamento de bits é o limite real (seção 9).

---

## 6. Saídas / atuadores (fora do escopo de entradas, registrado por afetar o orçamento de GPIO)

### LED do botão Start Engine

Botão momentâneo iluminado (aro cromado, tampa vermelha "ENGINE START", LED
interno), modelo comum de sites chineses de sim racing, **3 terminais**: o
LED e a chave compartilham um pino comum (COM), que faz parte tanto do
circuito da chave quanto do cátodo do LED.

Identificação dos 3 pinos com multímetro (antes de soldar):
1. Modo continuidade, testar os 3 pares **com o botão pressionado** — o par
   que fecha só nesse instante é COM + pino da chave.
2. Modo diodo, testar os pares restantes sem pressionar — o par que acende
   fraco e mostra ~1,8–2,2V (numa polaridade) é o LED; ponta vermelha nesse
   teste = ânodo (+), ponta preta = cátodo (COM).
3. O pino que aparece nos dois testes é o COM compartilhado.

Ligação:

| Terminal do botão | Vai para | Observação |
|---|---|---|
| COM (comum, chave+LED) | GND | Um único fio de GND serve pros dois circuitos |
| Chave (NO) | 74HC4067 C11 | Já alocado na seção 1/3 — pull-up interno da ESP32 na linha SIG, lê LOW ao pressionar |
| LED (ânodo, +) | **GPIO2** do ESP32-S3, através de resistor de **220 Ω** (ou 150 Ω para mais brilho) | Saída digital dedicada — permite o firmware decidir quando acender (sempre ligado, só com ignição em ON/IGN, piscando durante o crank etc.) em vez de fiar direto num trilho de alimentação |

Resistor calculado para os 3,3 V do GPIO do ESP32-S3 (não usar o trilho de
5V direto no GPIO): `R = (3,3V − Vf_LED) / I_desejada`, com `Vf` típico de
LED vermelho ≈ 2,0V e corrente-alvo 6–9 mA → 220–150 Ω. Não usar resistor
menor que ~100 Ω, para não ultrapassar a corrente segura por pino do
ESP32-S3.

GPIO2 sai da lista de "livres" (seção 5) — reservado para este LED.

---

## 7. Lógica de mapeamento — freio de estacionamento (Euro Truck Simulator)

Comportamento confirmado pelo usuário: o manete é um switch de 2 posições
**estáveis** (não é momentâneo como a chave de ignição) — **para baixo =
freio de estacionamento acionado**, **para cima = freio liberado**.

Ponto de atenção para quando for portar o firmware: o bind padrão do
Euro/American Truck Simulator para freio de estacionamento é um **toggle**
(a tecla/botão alterna o estado a cada pressionada, não segura um nível).
Um switch físico de 2 posições estáveis não bate diretamente com esse
modelo — se o firmware simplesmente espelhasse o nível do switch para o
bit do HID (nível baixo = bit 1 mantido, nível alto = bit 0 mantido), o jogo
receberia isso como "segurar o botão", o que não é o que o toggle espera.

**Decidido com o usuário: opção 1.** Firmware gera um pulso só na transição
de estado do switch (não espelha o nível):
- borda **up→down**: dispara um pulso único de "toggle" — assume que isso
  aciona o freio no jogo;
- borda **down→up**: dispara outro pulso único de "toggle" — assume que isso
  libera o freio.

Isso mantém a posição física do manete sempre coerente com o estado do freio
no jogo, contanto que os dois comecem sincronizados (ex.: sessão sempre
inicia com o manete pra baixo / freio acionado, que é o padrão real de
caminhão parado).

**Implementado.** `updateTogglePulses()` em `src/main.cpp` — reaproveita o
mesmo mecanismo de pulso dos encoders (30ms high + 20ms low gap). Antes
disso, a integração HID da seção 10 tratava `INPUT_HANDBRAKE` igual a
qualquer outro botão de nível por descuido, o que é exatamente o
comportamento errado descrito acima; corrigido.

---

## 8. Lógica de mapeamento — encoders (decidido: virtual +/- fixo)

**Decidido com o usuário: os 4 KY-040 rodam sempre em modo botão virtual
+/-, sem modo eixo e sem troca de modo.** Não haverá combo de alternância
nem LED de feedback de modo — descartado deliberadamente por não valer a
complexidade extra (4 LEDs, fiação, lógica de sincronização de estado) para
um caso de uso que a maioria dos jogos de simulação não usa (quase todo bind
relevante — cruise control, limpador, espelho, rádio etc. — aceita
tecla/botão discreto; muito poucos aceitam eixo diretamente).

Comportamento (ainda não implementado, só especificado):
- Cada detente de rotação **no sentido horário** gera um pulso momentâneo em
  um botão virtual "+" (apertar e soltar).
- Cada detente **no sentido anti-horário** gera um pulso momentâneo em um
  botão virtual "−", separado do "+".
- Portanto cada encoder ocupa **2 bits do bitmask de botões do HID**
  (um para +, um para −), além do bit do seu próprio SW (clique), que já
  está mapeado como botão normal no 74HC4067 (seção 1/3).
- Sem eixo, sem modo alternativo, sem LED de status de modo — decisão
  fechada para este projeto.

---

## 9. Orçamento de bits do HID (verificação de capacidade)

O HID report descriptor atual do firmware (`docs/ARCHITECTURE.md` item 7)
**não deve ser alterado** — expõe um bitmask fixo de 32 botões
(`uint32_t buttons`). Verificação de que todo o mapeamento decidido até
aqui cabe nesse limite sem precisar mexer no descriptor:

| Origem | Bits |
|---|---|
| Push buttons 1–11 | 11 |
| SW dos 4 encoders (clique) | 4 |
| Start Engine | 1 |
| Ignição — ON | 1 |
| Ignição — IGN | 1 |
| Chaves caça 1–4 | 4 |
| Freio de estacionamento (pulso de toggle) | 1 |
| Encoders — botão virtual +/- (4 × 2) | 8 |
| **Total usado** | **31** |
| Bits livres no HID atual | **1** |

Cabe dentro dos 32 bits existentes, sem exigir mudança no HID descriptor —
compatível com a restrição de não alterar HID/USB descriptors herdada da
baseline anterior. Sobra apenas **1 bit livre** no descriptor atual.

**Opção de expansão confirmada pelo usuário**: se o orçamento de 32 bits for
insuficiente no futuro, o usuário já tem um perfil/descriptor de referência
com **64 slots de botão** disponível para usar como base. Ou seja, o limite
de 32 bits **não é definitivo** — é só o que o firmware atual usa; ampliar
para 64 botões é uma opção real, já disponível, quando/se for necessário.

Importante: isso **é**, por definição, uma alteração do HID report
descriptor (o `uint32_t buttons` do `USBHIDGamepad` teria que virar um
bitmask maior — 64 bits, tipicamente 2× `uint32_t` ou um `uint8_t[8]` em um
report customizado, já que a lib `USBHIDGamepad` do core Arduino-ESP32 usada
hoje é fixa em 32 botões via `TUD_HID_REPORT_DESC_GAMEPAD`). Portanto essa
mudança:
- **Não é necessária agora** — o mapeamento atual cabe nos 32 bits existentes.
- Quando for feita, é uma decisão de firmware deliberada e isolada (trocar o
  report descriptor + a lógica de envio), não uma alteração incidental —
  exatamente o tipo de mudança que a baseline pede pra tratar com cautela,
  só que agora com autorização explícita do usuário para fazê-la **se e
  quando** o 32º bit acabar sendo insuficiente.

---
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

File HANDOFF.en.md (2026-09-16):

[🇧🇷 Português](HANDOFF.md) | 🇺🇸 English

# Button Box — context and handoff

## Goal
USB button box for SimHub: HID Game Controller with 32 buttons + encoders,
recognized in Windows' `joy.cpl`.

---

## Part 1 — STM32F103 (abandoned). What was investigated

Project: `~/Projects/arduino/STM32-SimHub-ButtonBox` (PlatformIO + TinyUSB + stm32cube).
Composite USB: HID gamepad (32 buttons, Report ID 1) + CDC ACM.

**Symptom:** the device enumerates and shows up in `joy.cpl` with 32
buttons, status OK, but NO button triggers — not even a heartbeat
generated by the firmware itself that toggles button 31 every 1s. The CDC
worked fine (PING/PONG responding).

### Measurements taken via SWD (ST-Link + OpenOCD, with the CPU running)

- The firmware **reads the pin and builds the correct report**:
  `s_report_work` with bit0=1 when closing the GND→PB9 jumper.
- `send_count` **increments** (reports accepted and transmitted by the USB
  stack).
- HID IN endpoint (TinyUSB mapped it to `EP1R` with `EA=3`):
  **`STAT_TX=VALID` stuck** — the report stays loaded in the buffer and
  the host **stops sending IN tokens**.
- Clock **exactly 48 MHz**: `RCC_CR` with HSERDY+PLLRDY, `RCC_CFGR` with
  PLL×9 and USBPRE=/1.5.
- USB IRQ enabled in the NVIC, no stuck interrupt, active bus (SOF), no
  suspend.
- Report descriptor read from the binary — textbook, no error:
  `05 01 09 05 A1 01 85 01 05 09 19 01 29 20 15 00 25 01 75 01 95 20 81 02 C0`
- R10 (D+ pull-up) measured by the user: **1.5 kΩ** (correct).
- **The number of reports delivered before it locks up is RANDOM**: 7, 8,
  14, 23, 68, 90, 337. Not a deterministic limit — it's an intermittent
  failure.

### Attempts that did NOT fix it

1. Disconnect pulse on D+ (PA12 low for 50 ms) at boot. *Fixed a
   different, real problem* — without it, after flashing via SWD the host
   doesn't re-enumerate and the device stays in a stale state (`cfg=0`
   stuck) until a physical replug. Verified: with the pulse, `cfg` goes
   to 1 on its own. But it didn't fix the buttons.
2. Implementing `tud_hid_get_report_cb` (it was a stub returning 0).
3. Removing the Report ID from the descriptor and sending without a
   prefix.
4. Adding a dummy X/Y axis — `joy.cpl` started showing "2 axes and 32
   buttons", but buttons still didn't trigger.
5. Changing the PID several times (0007→000A) to defeat Windows'
   descriptor cache.
6. Lowering the polling rate: `bInterval` 8→32 ms gave the identical
   failure; 64 ms made Windows **de-configure** the device (`cfg=0`).
7. **HID-only** build (no CDC, no IAD, 1 interface): **identical
   failure** — so composing with CDC isn't the variable.

### Likely cause: the MCU is a clone

Read via SWD:
- `DBGMCU_IDCODE = 0x20030410`
- Flash-size register = **128 KB** on a chip sold as a C8 (64 KB)
- **96-bit UID at `0x1FFFF7E8` = ALL ZERO**

A genuine ST STM32F103 always has a unique factory UID. A zeroed UID
means CKS32/CS32/APM32. The observed pattern (CDC **bulk** endpoints
work, HID **interrupt IN** endpoint never sustains) is consistent with a
USB quirk in these clones.

### STM32 project status
**Reverted to the original** at the user's request, and the original
composite firmware was reflashed onto the board. No experimental change
was left in place.

---

## Part 2 — Decision to switch boards

Hard constraint raised before investing more time:
- **ESP32-C3 / C6** (the best-selling "Super Mini"): native USB is a
  fixed-function *USB Serial/JTAG* → CDC only. **No HID.** Dead end.
- **ESP32-S2 / S3**: full USB OTG → TinyUSB → **HID works**.

Confirmed via esptool that the user's board is an **ESP32-S3 (QFN56) rev
v0.2, 4 MB XMC flash, 2 MB quad PSRAM, 40 MHz crystal**.

Deciding factor: the user **already had working HID gamepad code** in
`~/Projects/arduino/ESP-SimHub-ESP32S3-SCREEN/src/main_buttons.cpp`
(`USBHIDGamepad`, 32 buttons + 4 axes).

### Result
Test project: `~/Projects/arduino/esp32s3-buttonbox-test`

**HID WORKS.** macOS attached the driver (`PrimaryUsage=5` = Gamepad) and
`InputReportCount` keeps climbing (126→134→143). On Windows, Button 32
blinks in `joy.cpl`. A direct contrast with the STM32.

---
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

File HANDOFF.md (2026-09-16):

🇧🇷 Português | [🇺🇸 English](HANDOFF.en.md)

# Button Box — contexto e handoff

## Objetivo
Button box USB para SimHub: HID Game Controller com 32 botões + encoders,
reconhecido no `joy.cpl` do Windows.

---

## Parte 1 — STM32F103 (abandonado). O que foi investigado

Projeto: `~/Projects/arduino/STM32-SimHub-ButtonBox` (PlatformIO + TinyUSB + stm32cube).
USB composto: HID gamepad (32 botões, Report ID 1) + CDC ACM.
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

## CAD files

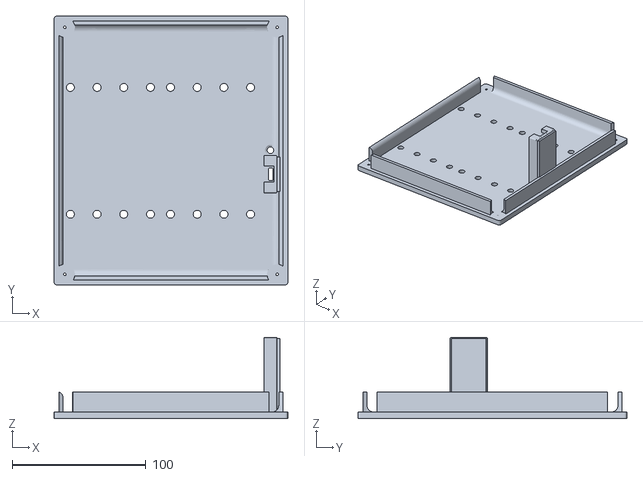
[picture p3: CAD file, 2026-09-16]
assets/STL/rear.stl
175.0 x 201.5 x 61.0

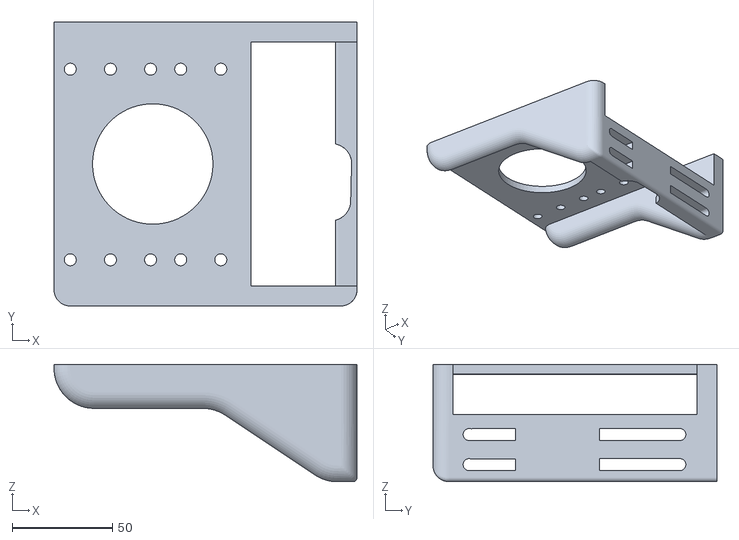
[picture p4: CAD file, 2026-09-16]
assets/STL/stand.stl
151.0 x 141.5 x 58.5

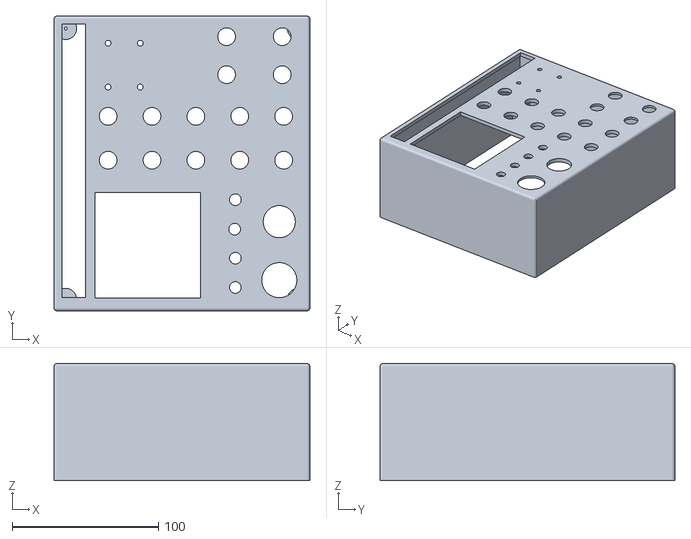
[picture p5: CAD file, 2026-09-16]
assets/STL/front.stl
175.0 x 201.5 x 80.0

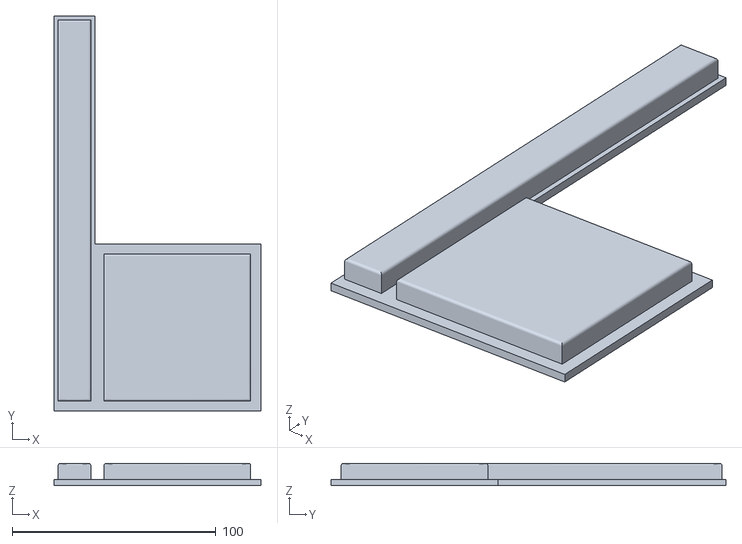
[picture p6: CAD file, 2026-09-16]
assets/STL/LED holder.stl
101.5 x 194.0 x 11.0

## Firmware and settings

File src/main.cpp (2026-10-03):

// Button box USB HID (ESP32-S3) + WiFi + OTA.
//
// Lições que este firmware incorpora, todas aprendidas na marra:
//
//  1. USB HID sobe PRIMEIRO. O button box tem que funcionar mesmo sem rede.
//  2. Sem portal cativo no caminho normal: as credenciais vêm de secrets.h e
//     o WiFi reinsiste sozinho para sempre. O portal só abre se você pedir
//     (segurando BOOT por 5 s) — antes ele abria sozinho a cada falha e a
//     placa ficava presa em modo AP, offline, sem reconectar nunca mais.
//  3. WiFi.setSleep(false) só DEPOIS de WiFi.begin(). Chamado antes, ele
//     inicializa o rádio em STA e impede o AP de subir. E tem que ser
//     REAPLICADO a cada reconexão (onWifiConnected) — aplicar uma vez só, no
//     startOta(), deixava o power save voltar sozinho depois de qualquer
//     queda de rede.
//  4. Economia de energia desligada: com ela o ping de LAN variava de 66 ms a
//     355 ms, e o OTA corrompia no meio da transferência.
//
// Botões 1-31: entradas reais da Button Box (MCP23017 + 74HC4067 +
// encoders), via a camada unificada lib/inputs — mapa completo logo
// abaixo. O botão BOOT da própria placa (GPIO0) NÃO alimenta mais nenhum
// bit do HID (isso era só um valor simulado de bring-up); ele continua
// servindo só para o gesto de abrir o portal de WiFi (segurar 5 s).
//
// Console na serial (COM do Windows): PING -> PONG, VERSION, IP
#include <Arduino.h>
#include <WiFi.h>
#include <ESPmDNS.h>
#include <ArduinoOTA.h>
#include <WiFiManager.h>
#include "USB.h"
#include "USBHIDGamepad.h"
#include "secrets.h"
#include "esp32-hal-tinyusb.h" // usb_persist_restart() — ver nota no comando BOOTLOADER
#include "esp_system.h"
#include <Preferences.h>   // NVS: persistir brilho dos LEDs entre boots
#include "inputs.h" // camada unificada de entradas (MCP23017+74HC4067+encoders)
#include "simhub.h" // protocolo Standard Serial do SimHub, sobre o mesmo CDC
#include "ws2812.h" // driver da fita/matriz WS2812 (RMT) — so desenha, nao conhece SimHub
#include "led_idle.h" // animacao de espera — so usada com o SimHub desconectado
#include "board_config.h" // mapa unico de pinos deste projeto — mude so aqui pra outra placa

USBHIDGamepad Gamepad;

// NVS: namespace "bbox", chave "brightness". Preferences e' thread-safe
// entre o loop e callbacks do WiFiManager (que roda em outra task), mas
// aqui so escrevemos do loop — sem risco de concorrencia.
static Preferences g_prefs;

// Carrega o brilho do NVS e aplica no driver; usado so no setup().
static void nvsLoadBrightness() {
  g_prefs.begin("bbox", /*readOnly=*/false);
  const uint8_t saved = g_prefs.getUChar("brightness", WS2812_BRIGHTNESS_DEFAULT_PCT);
  g_prefs.end();
  ws2812_set_brightness(saved); // grama automaticamente para 25-75
  Serial.printf("[brightness] carregado do NVS: %u%%\n", ws2812_get_brightness());
}

// Salva o brilho atual no NVS. So chama depois de ws2812_set_brightness().
static void nvsSaveBrightness() {
  g_prefs.begin("bbox", /*readOnly=*/false);
  g_prefs.putUChar("brightness", ws2812_get_brightness());
  g_prefs.end();
}


// Mapa explicito: INPUT LOGICAL ID (lib/inputs/inputs.h) -> bit do HID
// (uint32_t buttons do USBHIDGamepad). Regra unica e verificavel: o bit
// usado e o proprio valor numerico do InputId (0-30) — o enum ja e 0-based
// e sequencial, entao nao existe indireção nem tabela separada para
// desatualizar. Bit 31 (Botao 32) fica LIVRE — era do heartbeat de bring-up,
// removido depois que os 31 controles reais passaram a responder.
//
//   INPUT LOGICAL ID                 -> HID BUTTON (bit / Nº no joy.cpl)
//   INPUT_BUTTON_01                  -> bit 0  / Botao 1
//   INPUT_BUTTON_02                  -> bit 1  / Botao 2
//   INPUT_BUTTON_03                  -> bit 2  / Botao 3
//   INPUT_BUTTON_04                  -> bit 3  / Botao 4
//   INPUT_BUTTON_05                  -> bit 4  / Botao 5
//   INPUT_BUTTON_06                  -> bit 5  / Botao 6
//   INPUT_BUTTON_07                  -> bit 6  / Botao 7
//   INPUT_BUTTON_08                  -> bit 7  / Botao 8
//   INPUT_BUTTON_09                  -> bit 8  / Botao 9
//   INPUT_BUTTON_10                  -> bit 9  / Botao 10
//   INPUT_BUTTON_11                  -> bit 10 / Botao 11
//   INPUT_BUTTON_12 (SW encoder 1)   -> bit 11 / Botao 12
//   INPUT_BUTTON_13 (SW encoder 2)   -> bit 12 / Botao 13
//   INPUT_BUTTON_14 (SW encoder 3)   -> bit 13 / Botao 14
//   INPUT_BUTTON_15 (SW encoder 4)   -> bit 14 / Botao 15
//   INPUT_IGNITION_ON                -> bit 15 / Botao 16  [pulso, nao nivel — toggle do ETS2/ATS ("Ligar/Desligar Eletricidade"), ver TOGGLE_PULSE_IDS]
//   INPUT_IGNITION_IGN               -> bit 16 / Botao 17  [partida do motor de verdade — bind "Ligar/Desligar Motor" do ETS2/ATS]
//   INPUT_START_ENGINE               -> bit 17 / Botao 18  [botao iluminado avulso — sem destino fixo, livre pra qualquer jogo/função]
//   INPUT_HANDBRAKE                  -> bit 18 / Botao 19  [pulso, nao nivel — toggle do ETS2/ATS, ver TOGGLE_PULSE_IDS]
//   INPUT_KILL_SWITCH_01             -> bit 19 / Botao 20  [pulso, nao nivel — toggle do ETS2/ATS, ver TOGGLE_PULSE_IDS]
//   INPUT_KILL_SWITCH_02             -> bit 20 / Botao 21  [pulso, nao nivel — toggle do ETS2/ATS, ver TOGGLE_PULSE_IDS]
//   INPUT_KILL_SWITCH_03             -> bit 21 / Botao 22  [pulso, nao nivel — toggle do ETS2/ATS, ver TOGGLE_PULSE_IDS]
//   INPUT_KILL_SWITCH_04             -> bit 22 / Botao 23  [pulso, nao nivel — toggle do ETS2/ATS, ver TOGGLE_PULSE_IDS]
//   INPUT_ENCODER_01_CW              -> bit 23 / Botao 24  [pulso, nao nivel]
//   INPUT_ENCODER_01_CCW             -> bit 24 / Botao 25  [pulso, nao nivel]
//   INPUT_ENCODER_02_CW              -> bit 25 / Botao 26  [pulso, nao nivel]
//   INPUT_ENCODER_02_CCW             -> bit 26 / Botao 27  [pulso, nao nivel]
//   INPUT_ENCODER_03_CW              -> bit 27 / Botao 28  [pulso, nao nivel]
//   INPUT_ENCODER_03_CCW             -> bit 28 / Botao 29  [pulso, nao nivel]
//   INPUT_ENCODER_04_CW              -> bit 29 / Botao 30  [pulso, nao nivel]
//   INPUT_ENCODER_04_CCW             -> bit 30 / Botao 31  [pulso, nao nivel]
//   (livre)                          -> bit 31 / Botao 32
//
// HID report descriptor NAO foi alterado (continua uint32_t buttons via
// USBHIDGamepad, 32 bits, sem eixos/hat usados) — os 31 IDs cabem no
// espaço que ja existia, exatamente como verificado em
// docs/INPUTS_PINOUT.md secao 9 antes desta integracao.

// Pulso momentaneo dos encoders: INPUT_ENCODER_xx_CW/CCW só existem como
// EVENTO (lib/inputs não tem "nível" pra rotação) — aqui cada evento
// pendente vira um pulso no bit do HID: sobe por PULSE_HIGH_MS, desce e
// fica em LOW por pelo menos PULSE_LOW_GAP_MS antes do próximo pulso poder
// começar. Isso garante uma borda de subida E de descida visível pro host
// mesmo com vários detents em sequência rápida (o jogo/SimHub vê "aperta e
// solta" um número exato de vezes, nunca um "segurando contínuo").
enum class EncoderPulsePhase : uint8_t { Idle, High, LowGap };
struct EncoderPulseState {
  EncoderPulsePhase phase = EncoderPulsePhase::Idle;
  uint32_t          phaseUntilMs = 0;
};
// indice i (0-7) corresponde ao InputId (INPUT_ENCODER_01_CW + i)
static EncoderPulseState encoderPulse[8];

static const uint32_t ENCODER_PULSE_HIGH_MS    = 30;
static const uint32_t ENCODER_PULSE_LOW_GAP_MS = 20;

// Entradas de nivel que precisam virar PULSO DE TOGGLE em vez de nivel
// espelhado, porque a ACAO do jogo em que serao bindadas espera "aperta e
// alterna" (toggle por evento), nao "segura enquanto ligado" -- mas o
// hardware fisico delas e' um switch de posicao MANTIDA (liga e fica),
// nao um botao momentaneo. Se o HID so espelhasse o nivel do switch, o
// jogo veria "segurando o botao" enquanto a chave ficasse na posicao ON, o
// que nao dispara um novo toggle quando ela volta pra OFF -- o estado no
// jogo destrava do estado fisico da chave.
//
// Caso conhecido e documentado hoje: freio de estacionamento do
// Euro/American Truck Simulator, bind padrao e' toggle (docs/
// INPUTS_PINOUT.md secao 7).
//
// As 4 chaves caca entram na mesma lista POR PADRAO: quase todo acessorio
// de caminhao no ETS2/ATS (pisca-alerta, giroflex, luz de teto, travamento
// de diferencial, faroil extra, etc.) e' um bind de TOGGLE no jogo -- e o
// tipo de chave escolhido aqui (alavanca/bat, fica na posicao) e'
// justamente pra esse uso. Se algum dia uma delas for bindada a uma acao
// do tipo HOLD (efeito so existe enquanto segura, tipo buzina) em vez de
// toggle, TIRE o InputId dela desta lista -- nivel volta a ser o certo
// nesse caso especifico.
//
// INPUT_IGNITION_ON TAMBEM entra na lista: o ETS2/ATS tem sim um bind
// nativo pra ela -- "Ligar/Desligar Eletricidade do Motor" (liga o
// painel/GPS sem girar o motor), que E' toggle, confirmado pelo usuario a
// partir do proprio menu de Teclas e Botoes do jogo. A chave fisica
// (posicao 2 do conjunto tipo scooter) e' mantida, entao tem exatamente o
// mesmo problema do freio. IMPORTANTE: isto so afeta o BIT do HID que vai
// pro jogo -- updateStartEngineLed() le inputs_get_state(INPUT_IGNITION_ON)
// direto (nao o bit do HID), entao o LED continua acompanhando a POSICAO
// FISICA da chave normalmente, sem nenhum efeito colateral desta mudanca.
//
// INPUT_IGNITION_IGN (o contato que so fecha durante o giro/partida) e
// INPUT_START_ENGINE (o botao iluminado separado) ficam DE FORA de
// proposito: os dois ja sao fisicamente momentaneos (o botao solta
// sozinho; o contato IGN, numa chave com retorno por mola pra posicao 2 --
// tipico de chave de partida tipo scooter -- tambem so fica fechado
// enquanto voce segura), entao um aperto/giro breve ja produz a borda que
// um toggle espera, sem precisar de conversao.
//
// Uso pretendido (decidido com o usuario):
//   - INPUT_IGNITION_IGN (Botao 17): partida do motor de VERDADE -- bind
//     "Ligar/Desligar Motor" do ETS2/ATS. E' o giro da propria chave, igual
//     carro/caminhao de verdade (ON liga eletrica, girar mais da partida).
//   - INPUT_START_ENGINE (Botao 18): botao ILUMINADO separado, livre pra
//     qualquer funcao -- outro jogo de corrida com botao de partida
//     proprio, ou qualquer outra coisa que precisar de um push button
//     extra. Nao tem destino fixo no ETS2/ATS.
// Nenhum dos dois exige mudanca de firmware pra nenhuma dessas funcoes --
// nivel momentaneo ja serve pra qualquer bind (toggle ou hold), a escolha
// de destino e' feita 100% dentro de cada jogo.
//
// Mecanismo: qualquer troca de posicao da chave -- PRESSED OU RELEASED,
// as duas direcoes -- dispara UM pulso momentaneo no bit (30ms high +
// 20ms low gap, mesmas constantes e mesma maquina de estados dos
// encoders). Isso mantem a posicao fisica da chave sempre coerente com o
// estado no jogo, contanto que os dois comecem sincronizados.
static const InputId TOGGLE_PULSE_IDS[] = {
  INPUT_IGNITION_ON,
  INPUT_KILL_SWITCH_01,
  INPUT_KILL_SWITCH_02,
  INPUT_KILL_SWITCH_03,
  INPUT_KILL_SWITCH_04,
  INPUT_HANDBRAKE,
};
static const uint8_t TOGGLE_PULSE_COUNT =
    sizeof(TOGGLE_PULSE_IDS) / sizeof(TOGGLE_PULSE_IDS[0]);
static EncoderPulseState togglePulse[TOGGLE_PULSE_COUNT];

static void updateTogglePulses(uint32_t &buttons, uint32_t now) {
  for (uint8_t i = 0; i < TOGGLE_PULSE_COUNT; i++) {
    const InputId      id  = TOGGLE_PULSE_IDS[i];
    const uint32_t      bit = (1UL << (uint8_t)id);
    EncoderPulseState &p   = togglePulse[i];

    switch (p.phase) {
      case EncoderPulsePhase::Idle: {
        const InputEventType ev = inputs_get_event(id);
        if (ev == INPUT_EVENT_PRESSED || ev == INPUT_EVENT_RELEASED) {
          p.phase = EncoderPulsePhase::High;
          p.phaseUntilMs = now + ENCODER_PULSE_HIGH_MS;
          buttons |= bit;
        } else {
          buttons &= ~bit;
        }
        break;
      }
      case EncoderPulsePhase::High:
        buttons |= bit;
        if ((int32_t)(now - p.phaseUntilMs) >= 0) {
          p.phase = EncoderPulsePhase::LowGap;
          p.phaseUntilMs = now + ENCODER_PULSE_LOW_GAP_MS;
          buttons &= ~bit;
        }
        break;
      case EncoderPulsePhase::LowGap:
        buttons &= ~bit;
        if ((int32_t)(now - p.phaseUntilMs) >= 0) {
          p.phase = EncoderPulsePhase::Idle;
        }
        break;
    }
  }
}

// Confere se um InputId esta na lista TOGGLE_PULSE_IDS acima (usado pra
// excluir esses IDs do espelhamento de nivel generico, ja que
// updateTogglePulses() cuida deles sozinho).
static bool isTogglePulseId(InputId id) {
  for (uint8_t i = 0; i < TOGGLE_PULSE_COUNT; i++) {
    if (TOGGLE_PULSE_IDS[i] == id) return true;
  }
  return false;
}
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
void loop() {
  // wm.process() retorna true assim que conecta na rede nova escolhida no
  // portal -- so' ai' devolve o controle pro wifiKeepAlive() normal
  // (guardado por `if (portalAtivo) return;`). Sem isso, portalAtivo ficava
  // true pra sempre depois do primeiro sucesso.
  if (portalAtivo && wm.process()) {
    portalAtivo = false;
    Serial.println("[WiFi] portal: rede salva e conectada");
  }
  onWifiConnected(); // reaplica setSleep(false) e sobe o OTA na (re)conexao
  if (otaReady) ArduinoOTA.handle();

  // Durante a atualizacao NADA mais roda: qualquer escrita na serial pode
  // bloquear no CDC e matar a transferencia.
  if (otaRunning) return;

  wifiKeepAlive();
  serialCommands();
  statusReport();

  inputs_update(); // MCP23017 + 74HC4067 + 4x KY-040 — nao bloqueia (lib/inputs)
  simhub_update(); // so verifica timeout de conexao — nao le Serial, nao bloqueia

  updateMatrixWalk(); // so faz algo com MATRIXWALK ligado; ve comentario acima

  // Ponte SimHub -> WS2812: o UNICO lugar do firmware que conhece os dois
  // ao mesmo tempo (nem lib/simhub nem lib/ws2812 se conhecem — regra 9 da
  // arquitetura). Reenvia o framebuffer inteiro a cada iteracao do loop;
  // como ws2812_show() e' assincrono (rmtWrite, nao bloqueia) e o loop ja
  // tem um piso de ~5ms (delay(5) no final), isso nunca chama de novo
  // antes da transmissao anterior (~2,2ms para 74 LEDs) terminar.
  //
  // Layout fisico: UMA cadeia WS2812 so — a matriz 8x8 primeiro (pixels
  // 0-63), a fita logo depois (DOUT da matriz -> DIN da fita). Pro SimHub
  // eles continuam sendo dois dispositivos logicos separados (RGB Matrix e
  // RGB Leds); quem junta os dois numa cadeia unica e' este trecho.
  {
    static Ws2812Color ledBuf[WS2812_MAX_LEDS];

    // Sem SimHub conectado (recem-ligado, ou SimHub fechado ha mais de 5 s)
    // os framebuffers dele estao zerados — em vez de deixar tudo apagado,
    // mostra a animacao de espera (lib/led_idle). Assim que o SimHub voltar
    // a falar com a placa, simhub_is_connected() fica true e as cores dele
    // assumem na hora. A animacao nao e' efeito de jogo: so existe nesse
    // estado, e LED_IDLE_BRIGHTNESS = 0 (em led_idle.h) a desliga.
    static LedIdleColor idleMatrix[SIMHUB_MATRIX_LED_COUNT];
    static LedIdleColor idleStrip[SIMHUB_STRIP_COUNT_MAX];
    const bool idle = !simhub_is_connected();
    const uint16_t stripCount = simhub_get_strip_count();
    uint16_t total = SIMHUB_MATRIX_LED_COUNT + stripCount;
    if (total > WS2812_MAX_LEDS) total = WS2812_MAX_LEDS;

    // Matriz/fita apagam com a ignicao em OFF, igual o LED do Start Engine
    // (updateStartEngineLed, mesma fonte: inputs_get_state(INPUT_IGNITION_ON)).
    // Decisao do usuario: o "painel" do carro inteiro desliga com a chave,
    // nao so o botao — nem SimHub nem a animacao de idle aparecem nesse
    // estado, exatamente como um painel de carro de verdade apaga com a
    // chave fora. MATRIXWALK continua funcionando com a ignicao desligada
    // de proposito — e' diagnostico manual, nao efeito normal de uso.
    const bool ignitionOn = inputs_get_state(INPUT_IGNITION_ON);

    if (g_matrixWalkPhys >= 0) {
      // MATRIXWALK ativo: ignora SimHub/idle/ignicao, acende só o indice
      // FISICO cru corrente, sem nenhum remapeamento — ver comentario de
      // g_matrixWalkPhys.
      for (uint16_t i = 0; i < SIMHUB_MATRIX_LED_COUNT; i++) {
        ledBuf[i] = (i == (uint16_t)g_matrixWalkPhys) ? Ws2812Color{255, 255, 255}
                                                       : Ws2812Color{0, 0, 0};
      }
      for (uint16_t j = 0; SIMHUB_MATRIX_LED_COUNT + j < total; j++) {
        ledBuf[SIMHUB_MATRIX_LED_COUNT + j] = {0, 0, 0};
      }
    } else if (portalAtivo) {
      // Portal de WiFi ativo (BOOT ou combo de botoes seguraram 5s):
      // respira azul na matriz+fita inteira, pra confirmar visualmente
      // "modo de configuracao" sem precisar abrir o monitor serial nem
      // adivinhar se o AP ButtonBox-Setup realmente subiu. Roda MESMO com
      // ignicao desligada (voce pode configurar o WiFi antes de ligar a
      // chave) — por isso este bloco vem ANTES do `!ignitionOn` abaixo.
      // Azul puro, periodo de ~2s, triangular — cor que nao aparece em
      // nenhum efeito normal do SimHub nem na animacao de idle.
      const uint32_t phase = millis() % 2000;
      const uint16_t level = (phase < 1000) ? phase : (2000 - phase);
      const uint8_t  b     = (uint8_t)(40 + (level * (255 - 40)) / 999);
      for (uint16_t i = 0; i < total; i++) ledBuf[i] = {0, 0, b};
    } else if (!ignitionOn) {
      // Ignicao OFF: tudo apagado, sem gastar tempo renderizando idle/
      // SimHub pra nada (led_idle_render nem e' chamado aqui).
      for (uint16_t i = 0; i < total; i++) ledBuf[i] = {0, 0, 0};
    } else {
      if (idle) {
        led_idle_render(millis(), idleMatrix, idleStrip, stripCount);
      }

      // Matriz: o SimHub manda os 64 pixels em ordem linear (linha a linha).
      // Tres correcoes de fiacao independentes, configuraveis em
      // board_config.h — ver o comentario la pra o que cada uma resolve.
      for (uint16_t i = 0; i < SIMHUB_MATRIX_LED_COUNT; i++) {
        uint16_t y = i / 8;
        uint16_t x = i % 8;
        if (BOARD_MATRIX_MIRROR_X) x = 7 - x;
        if (BOARD_MATRIX_MIRROR_Y) y = 7 - y;
        if (BOARD_MATRIX_SERPENTINE && (y % 2) == 0) x = 7 - x;
        const uint16_t phys = y * 8 + x;
        if (idle) {
          ledBuf[phys] = {idleMatrix[i].r, idleMatrix[i].g, idleMatrix[i].b};
        } else {
          const SimhubColor c = simhub_get_matrix_led(i);
          ledBuf[phys] = {c.r, c.g, c.b};
        }
      }

      // Fita, logo depois da matriz na mesma cadeia.
      for (uint16_t j = 0; SIMHUB_MATRIX_LED_COUNT + j < total; j++) {
        if (idle) {
          ledBuf[SIMHUB_MATRIX_LED_COUNT + j] = {idleStrip[j].r, idleStrip[j].g, idleStrip[j].b};
        } else {
          const SimhubColor c = simhub_get_strip_led(j);
          ledBuf[SIMHUB_MATRIX_LED_COUNT + j] = {c.r, c.g, c.b};
        }
      }
    }

    ws2812_show(ledBuf, total);
  }

  static uint32_t buttons  = 0;
  static uint32_t lastSent = 0xFFFFFFFFu;

  const uint32_t now = millis();

  // O heartbeat de bring-up que piscava o Botao 32 a cada 1 s FOI REMOVIDO:
  // ele existia so pra provar que o HID estava vivo enquanto o hardware nao
  // estava montado, e ja cumpriu esse papel. Com os 31 controles reais
  // respondendo, ele virava ruido — um botao "fantasma" que qualquer jogo ou
  // o SimHub poderia bindar por engano num aprendizado automatico.
  //
  // O bit 31 agora fica LIVRE (o descriptor continua com 32 botoes; e o 32o
  // que deixou de ser usado). E o primeiro slot disponivel se voce adicionar
  // um controle — ver o orcamento de bits em docs/INPUTS_PINOUT.md secao 9.

  // Entradas de nivel (botões, ignição, start, chaves caça): mapa
  // explicito no topo do arquivo — bit = (uint8_t)id. inputs_get_state()
  // já vem debounced (MCP23017/74HC4067 debouncam na própria camada).
  // IDs em TOGGLE_PULSE_IDS ficam de fora: são pulso de toggle, não nível
  // — ver updateTogglePulses() no topo do arquivo.
  for (uint8_t id = 0; id < INPUT_LEVEL_ID_COUNT; id++) {
    if (isTogglePulseId((InputId)id)) continue;
    const uint32_t bit = (1UL << id);
    if (inputs_get_state((InputId)id)) buttons |= bit;
    else                                buttons &= ~bit;
  }

  // Chaves de toggle (freio de estacionamento hoje; qualquer chave caça
  // que precisar entra na lista TOGGLE_PULSE_IDS, sem função nova): pulso
  // a cada troca de posição — ver updateTogglePulses() no topo do arquivo.
  updateTogglePulses(buttons, now);

  // Ajuste de brilho pelo encoder 1 (segura o SW + gira) — tem que vir
  // ANTES de updateEncoderPulses(), pra consumir os eventos do encoder 1
  // antes que virem pulso no HID. So faz algo com o SW do encoder 1
  // segurado; ver comentario de updateBrightnessControl() no topo.
  updateBrightnessControl();

  // Encoders: cada detent vira um pulso momentâneo (ver
  // updateEncoderPulses no topo do arquivo), nunca um nível.
  updateEncoderPulses(buttons, now);

  watchInputs(); // so faz algo com WATCH ligado; nao mexe no HID

  // LED do Start Engine acompanha a ignição (ver updateStartEngineLed no
  // topo). Nao mexe em 'buttons' — e' saida fisica, nao entra no HID.
  updateStartEngineLed();
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

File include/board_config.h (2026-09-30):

// board_config.h — MAPA ÚNICO de hardware deste projeto.
//
// Trocou de placa (ESP32 maior, outra variante) ou quer reaproveitar este
// firmware com pinos diferentes? **Só este arquivo precisa mudar.** Nenhum
// outro .cpp/.h do projeto tem pino/canal/endereço fixo "espalhado" —
// tudo (main.cpp, lib/inputs, e os firmwares de teste isolados
// mcp_test.cpp/mux_test.cpp/encoder_test.cpp/ws2812_test.cpp/
// inputs_test.cpp) lê os valores daqui.
//
// Os drivers de baixo nível (lib/mcp23017, lib/mux4067, lib/encoders,
// lib/ws2812) continuam genéricos e reutilizáveis sozinhos em QUALQUER
// outro projeto — eles não incluem este arquivo, só aceitam pino/endereço
// como parâmetro (com um default próprio, caso alguém use o driver isolado
// sem este arquivo). Este header é a "cola" específica deste projeto que
// decide quais valores passar pra cada um.
//
// ======================================================================
// REVISÃO 2 (set/2026) — "só até o GPIO13"
// ======================================================================
// A ESP32-S3 SuperMini só expõe em header de fácil acesso os GPIO 0-13. Do
// GPIO14 em diante (14-18, 21, 33-48) os sinais existem no módulo, mas
// saem em PADS na FACE INFERIOR da placa — soldáveis, porém sob o corpo da
// placa, o que inviabiliza montagem manual decente (isto inclui o próprio
// GPIO14, não só 15 pra cima). A revisão 1 deste mapa colocava as 5 linhas
// do 74HC4067 (S0-S3 + SIG) justamente em 15/16/17/18/21.
//
// Solução adotada (opção B, escolhida pelo usuário): os 8 sinais de
// quadratura dos 4 encoders SAEM do GPIO direto e passam para o banco A
// do MCP23017, liberando 8 pinos de header; o 74HC4067 assume as linhas
// de botão e ocupa 5 desses pinos livres. Resultado: **nenhum pino usado
// vai além do GPIO13**, e ainda sobram 11/12/13 livres.
//
// Consequência técnica que NÃO pode ser esquecida: quadratura por I2C não
// tem interrupção por borda, então a amostragem passou a ser feita por uma
// task dedicada (lib/inputs) a BOARD_MCP_SAMPLE_PERIOD_MS — ver o
// comentário dessa constante mais abaixo antes de mexer nela.
//
// Mapa físico completo, com o raciocínio de cada escolha, está em
// docs/INPUTS_PINOUT.md e docs/SYSTEM_INTEGRATION.md — este arquivo é só
// os números; a justificativa fica na documentação, pra não duplicar.
#pragma once
#include <stdint.h>

// ======================================================================
// MCP23017 (expansor de I/O via I2C)
//   Banco A (GPA0-GPA7) -> CLK/DT dos 4 encoders (quadratura)
//   Banco B (GPB0-GPB3) -> SW dos 4 encoders
//   Banco B (GPB4-GPB7) -> 4 chaves tipo caça
// ======================================================================
static const uint8_t  BOARD_I2C_SDA_PIN   = 8;
static const uint8_t  BOARD_I2C_SCL_PIN   = 9;
static const uint8_t  BOARD_MCP23017_ADDR = 0x20; // A0/A1/A2 no GND

// INT do MCP23017: NAO FIAR. Removido do mapa de proposito.
//
// O INT (INTA/INTB do chip) e a saida que o MCP23017 aciona sozinho quando
// uma entrada habilitada muda — serve para o MCU nao precisar ficar
// perguntando. Este firmware nunca habilita GPINTEN nem registra
// attachInterrupt: a amostragem e periodica (ver a constante abaixo), entao
// o INT nao tem funcao nenhuma aqui.
//
// Uma revisao anterior deste arquivo reservava o GPIO14 para ele. Era um
// erro duplo: alem de inutil, o GPIO14 na ESP32-S3 SuperMini/S3 Zero e um
// pad da face inferior — exatamente o tipo de pino que esta revisao existe
// para evitar. Se um dia a amostragem virar orientada a evento, escolha um
// GPIO de header LIVRE na epoca e declare aqui; nao volte pro 14.

// Período de amostragem do MCP23017 pela task dedicada de lib/inputs.
//
// Por que 1 ms (e por que NÃO pode virar 5 ms): um KY-040 tem 20 detents
// por volta e percorre o ciclo de Gray completo (4 transições) a cada
// detent. Num giro rápido de mão (~1,5 volta/s = 30 detents/s) um detent
// dura ~33 ms e suas 4 transições se espalham por ~5-10 ms entre si. A 1
// ms de amostragem todas são capturadas com folga; a 5 ms, duas transições
// vizinhas caem na MESMA amostra, a máquina de quadratura vê um salto de 2
// bits (fisicamente impossível), reseta pro repouso e o detent é PERDIDO.
// O loop() principal tem delay(5) no fim — é exatamente por isso que a
// amostragem NÃO pode morar nele e ganhou task própria.
//
// Custo: uma leitura de 2 bytes a 400 kHz gasta ~150 us, ou seja ~15% do
// barramento I2C, que não tem mais nenhum outro dispositivo. Aceitável.
static const uint32_t BOARD_MCP_SAMPLE_PERIOD_MS = 1;

// ======================================================================
// Encoders KY-040 — CLK/DT no banco A do MCP23017 (não mais em GPIO)
// Índices na convenção de bit do input_expander: 0-7 = GPA0-GPA7.
// ======================================================================
static const uint8_t BOARD_ENCODER_COUNT = 4;
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

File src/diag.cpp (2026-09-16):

// Diagnóstico: roda em ARDUINO_USB_MODE=1 (USB-Serial-JTAG de hardware).
// Só serve para responder "o app está rodando nesta placa?" — se estas linhas
// aparecerem na serial, a placa, o toolchain e a gravação estão OK, e o
// problema do HID fica isolado na troca para USB-OTG/TinyUSB.
#include <Arduino.h>

void setup() {
  Serial.begin(115200);
  delay(300);
  Serial.println();
  Serial.println("=== APP RODANDO (diag, USB_MODE=1) ===");
}

void loop() {
  static uint32_t n = 0;
  Serial.printf("alive %lu\n", (unsigned long)n++);
  delay(500);
}

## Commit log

2026-09-16 Firmware inicial: HID + WiFi/OTA + inputs unificados + SimHub + WS2812
    Button box ESP32-S3 com HID gamepad nativo, WiFi/OTA, camada unificada de
    inputs (MCP23017 + 74HC4067 + 4x KY-040), integracao com o protocolo
    Standard Serial do SimHub sobre o CDC existente, e driver WS2812 (RMT)
    para a matriz 8x8 + fita de LEDs.
    Claude-Session: https://claude.ai/code/session_01StgbigYDrBQESwgckkqW2H
2026-09-16 Adiciona comando DUMPLEDS e descoberta dinamica de LED count no script de teste
    DUMPLEDS imprime o framebuffer do SimHub recebido pela serial, sem
    depender do firmware isolado simhub-test nem de LEDs fisicos acesos.
    scripts/simhub_test_send.py agora descobre a contagem de LEDs via
    'ledsc' em vez de um valor fixo, evitando desincronizar com o SETLEDS
    ja gravado na placa.
    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
    [main.cpp, simhub_test.cpp, simhub_test_send.py]
2026-09-16 Atualiza BASELINE.md: teste SimHub confirmado ponta a ponta, item 3 obsoleto
    Confirma proto/ledsc/sleds funcionando no firmware de producao real (nao
    so no isolado), incluindo persistencia de SETLEDS sobrevivendo a um
    upload OTA. Marca o item 3 (BOOT = Botao 1) como desatualizado desde a
    integracao de lib/inputs.
    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
2026-09-16 Reescreve lib/simhub para o protocolo Arduino real do SimHub
    A implementacao anterior falava o protocolo do sketch legado de LEDs
    (0xFF x6 + proto/ledsc/sleds). O scanner da aba Arduino do SimHub usa
    outro protocolo: 0x03 + char de comando. Prova: o log do usuario mostrava
    "Hello (sending)" -> "Unrecognized" contra um firmware que respondia
    corretamente ao protocolo antigo.
    Protocolo novo extraido de ESP-SimHub (upstream e fork do usuario), que
    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
2026-09-16 Responde ao SimHub direto pela TinyUSB, contornando o gate de DTR do USBCDC
    Causa do "Unrecognized" no scan do SimHub, mesmo com o protocolo correto:
    USBCDC::write() do core descarta a escrita silenciosamente quando
    tud_cdc_n_connected() e falso, e isso depende do host assertar DTR. O
    SimHub abre a porta sem assertar DTR (assertar reseta placas Arduino de
    verdade), entao o firmware recebia o Hello — RX nao e' filtrado — e a
    resposta 'j' morria dentro do USBCDC antes de sair pro USB.
    Evidencia: log do SimHub mostrando Hello (sending) -> Unrecognized (5x)
    enquanto scripts/simhub_test_send.py (pyserial, que assere DTR por
    padrao) passava em todos os comandos na mesma porta e firmware.
    As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
2026-09-16 Implementa a camada de transporte ARQ do SimHub
    Faltava a camada que o SimHub usa por baixo dos comandos: ele nao manda
    0x03 cru na serial, encapsula tudo em pacotes ARQ com id e CRC8 e espera
    um ACK por pacote. Descoberto pelo stack trace no log do usuario
    (ArqSerialLib.ArqSerial.Open()).
    Host -> device: 01 01 <id> <len> <dados> <crc8>
    Device -> host: ACK 03 <id> | NACK 04 <ultimoValido> <motivo>
    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
2026-09-16 Centraliza todo pinout em include/board_config.h
    Antes, cada driver (mcp23017, mux4067, encoders, ws2812) tinha seus
    proprios defaults e lib/inputs/main.cpp usavam esses defaults sem passar
    nada explicito -- trocar um pino exigia editar o .h de dentro da lib.
    Agora include/board_config.h e' o unico lugar com pino/canal/endereco
    deste projeto. lib/inputs e main.cpp leem de la e passam explicito pra
    cada _init(). Os drivers continuam genericos e reutilizaveis sozinhos
    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
2026-09-16 Adiciona README.md e include/secrets.h.example
    README.md vira a porta de entrada do repositorio: visao geral do
    hardware, diagrama de arquitetura, como compilar/gravar (USB e OTA), como
    testar cada componente isolado, tabela de comandos do console serial, e
    indice pra toda a documentacao em docs/. Aponta board_config.h como o
    unico lugar a editar pra trocar de placa/pinout -- e' a peca que faltava
    pra "outras pessoas conseguirem reaproveitar", motivo original da
    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
2026-09-16 Manual completo bilingue (PT-BR/EN) + case 3D + acessorios de terceiros
    README.md (PT-BR, canonico) e README.en.md (traducao) viram o manual
    completo do projeto: o que e', hardware eletronico, case impresso em 3D,
    acessorios compativeis de terceiros (freio de estacionamento e botao PTT
    de radio, linkados com credito aos autores originais), arquitetura,
    reaproveitamento via board_config.h, build/flash, teste isolado por
    componente, console serial, e indice pra toda a documentacao em docs/.
    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
    [LED holder.stl, front.stl, rear.stl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]
2026-09-16 Traduz toda a documentacao para ingles (PT-BR/EN em todos os docs)
    Cada doc (HANDOFF.md, docs/ARCHITECTURE.md, docs/BASELINE.md,
    docs/INPUTS_PINOUT.md, docs/SIMHUB_PROTOCOL.md, docs/SYSTEM_INTEGRATION.md)
    ganha uma contraparte .en.md e um link de troca de idioma na primeira
    linha, no mesmo padrao ja usado em README.md/README.en.md.
    Traducao completa de prosa e conteudo de tabelas; blocos de codigo
    fenced, valores hex, nomes de registrador/macro e caminhos de arquivo
    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
2026-09-16 Corrige referencias desatualizadas ao protocolo SimHub antigo (PT/EN)
    O fork que traduziu HANDOFF.md acabou tambem commitando as outras 5
    traducoes (alem do escopo pedido a ele) sem eu revisar antes -- ao
    revisar agora, achei conteudo desatualizado que sobreviveu a traducao
    por ser fidelidade correta ao .md fonte, nao erro da traducao em si:
    - docs/SYSTEM_INTEGRATION.md(.en): checklist de teste e inventario de
    delay() ainda citavam o protocolo antigo (proto/ledsc/sleds, 6x0xFF) e
    o timeout de 100ms -- ja substituidos pelo ARQ real e por 300ms desde
    a etapa de correcao do protocolo. Fork EN tinha sinalizado a
    discrepancia numa nota ao inves de corrigir (comportamento correto pro
    es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
2026-09-16 Adiciona secao de apoio (PicPay) nos dois READMEs
    Replica a secao "Support This Fork" do README do projeto irmao
    (ESP-SimHub-ESP32S3-SCREEN): PicPay @orlandoeduardo.pereira, links, e o
    QR code PIX (copiado pra assets/img/pix.png). Adicionada em PT-BR e EN,
    no final de cada README.
    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
2026-09-24 Corrige diagrama de soldagem: mux nao precisa de resistor por entrada
    A secao 11 (e a secao 3, e dois comentarios em lib/mux4067) afirmavam que
    cada entrada do 74HC4067 precisa de um resistor externo de 10k. Exagero:
    o firmware ja liga INPUT_PULLUP na linha SIG comum, que serve todos os
    canais, entao nenhum resistor por entrada e' necessario. Um unico resistor
    SIG->3V3 fica documentado como opcional, apenas se o mux-test mostrar
    leitura instavel (expectativa pela fisica do circuito, ainda nao medida
    no hardware montado).
    Seção 11 reescrita (PT e EN) com o que faltava e mais provavelmente faz
    "nada funcionar": 74HC4067 EN no GND, MCP23017 RESET no 3V3 e A0-A2 no
    GND, pull-ups do I2C, KY-04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
2026-09-24 fix(leds): adicionar lib led_idle e brilho WS2812 faltantes
    O commit 35d2f4e ("LED idle animation + brightness limiter") subiu so o
    src/main.cpp. As duas pecas de que ele depende ficaram de fora:
    - lib/led_idle/ (led_idle.cpp/.h) — nunca foi adicionada ao indice
    - lib/ws2812/ — o limitador de brilho (ws2812_set_brightness,
    ws2812_get_brightness, ws2812_scale_channel) ficou so no working tree
    Como main.cpp ja faz #include "led_idle.h" e chama ws2812_set_brightness(),
    origin/main nao compila desde aquele commit. Isto completa o 35d2f4e; nao ha
    mudanca de comportamento em relacao ao que ja rodava na bancada.
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2026-09-24 fix(pinout): remover INT do MCP23017 do mapa (GPIO14 nao e header)
    Eu tinha reservado o GPIO14 para o INT do MCP23017 "porque e de graca".
    Estava errado duas vezes:
    1. O firmware nunca habilita GPINTEN nem registra attachInterrupt — a
    amostragem e periodica (task dedicada, 1 ms). O fio nao faria nada.
    2. O GPIO14 na ESP32-S3 SuperMini/S3 Zero e pad da face inferior, igual
    aos 15-18 que motivaram esta revisao. Ou seja, eu mandei soldar embaixo
    num pino inutil, contrariando o proprio objetivo do rearranjo.
    INTA/INTB do MCP23017 agora ficam sem conexao (em varios breakouts, o
    CJMCU-2317 entre eles, essas saidas nem chegam ao header). O mapa passa a
    usar 10 GPIOs, todos na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
    [board_config.h]
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2026-09-25 fix(wifi): reaplicar setSleep(false) a cada reconexao e expor RSSI
    WiFi.setSleep(false) morava dentro de startOta(), que comeca com
    "if (otaReady) return;" — ou seja, era aplicado UMA vez na vida da placa.
    Depois de qualquer reconexao (queda do AP, roaming, setAutoReconnect ou o
    WiFi.disconnect()+begin() do wifiKeepAlive) ninguem reaplicava, e o power
    save podia voltar sozinho. A nota 4 do cabecalho do main.cpp ja avisava que
    economia de energia = ping instavel + OTA corrompendo no meio.
    Agora a borda de conexao e tratada em onWifiConnected(), chamada todo loop:
    reaplica setSleep(false) a cada (re)conexao e so entao sobe o OTA.
    Medido na bancada, mesma placa, mesma rede (2026-09-24):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
    [main.cpp]
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2026-09-25 feat(config): suportar mux active-high e LED do start em active-low
    O botao iluminado de start da bancada tem o COMUM amarrado no ANODO do LED
    (medido: positivo no pino 1 acende direto; positivo no pino 2 so acende com
    a chave fechada, porque a corrente passa pelo contato ate o pino 1).
    Isso cria um conflito que nao da pra resolver so em firmware: a chave quer o
    comum no GND pra ser lida active-low pelo mux, mas com o comum no GND o
    anodo fica em 0 V e o LED nunca acende. Ou o comum vai pra 3,3 V e as duas
    polaridades invertem juntas, ou o LED e' descartado.
    Duas constantes novas em board_config.h, ambas no default antigo (nada muda
    de comportamento ate alguem virar):
    BOARD_MUX_ACTIVE_H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
    [board_config.h, main.cpp]
2026-09-25 fix(config): ligar polaridade active-high do C11 e do LED do start
    O botao iluminado montado na bancada e comum-ANODO, confirmado por dois
    sintomas simultaneos com o firmware ainda em active-low: LED sempre aceso
    (o nivel "apagado" era LOW, que nessa fiacao e justamente o que acende) e
    Botao 18 sempre acionado (o pull-down de 4,7k deixa o C11 em GND em
    repouso, lido como "apertado").
    BOARD_MUX_ACTIVE_HIGH_MASK 0x0000 -> 0x0800 (bit 11 = C11)
    BOARD_START_ENGINE_LED_ACTIVE_LOW false -> true
    A secao 11 do INPUTS_PINOUT passa a documentar as DUAS variantes do botao,
    com a constante correspondente de cada uma e os dois sintomas acima como
    pista de diagnostico — antes so existia a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
    [board_config.h]
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2026-09-29 fix(config): BOARD_MUX_ACTIVE_HIGH_MASK 0x0800->0x0000, LED active-low false
    O pino C11 (Start Engine) estava com active-high mas sem pull-down externo
    confiavel ligado diretamente ao pino do chip — o pull-up interno do SIG
    dominava e o botao 18 ficava sempre pressionado no joy.cpl, mesmo com
    o plug removido do canal.
    Tratamento: todos os canais agora sao active-low (mask=0x0000), o que
    e' o padrao do projeto e o que o hardware real tem (COM->GND). O LED
    do Start Engine passa para active-high (LED_ACTIVE_LOW=false): GPIO2
    fornece corrente, COM/catodo no GND — compativel com a secao 6 e 11
    dos docs.
    docs: aviso em destaque sobre o pino EN do 74HC4067 (PT + EN)
    O pino EN (ativo em LOW)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
    [board_config.h]
2026-09-29 docs: corrige inconsistências da Revisão 2 do pinout (auditoria código-vs-doc)
    - README.md/.en.md: tabela de hardware e diagrama ASCII ainda descreviam a
    Revisão 1 (push buttons/ignição/Start Engine no MCP23017, encoders direto
    na MCU). Corrigido para o mapa real: encoders (CLK/DT/SW) + chaves caça no
    MCP23017; push buttons/ignição/Start Engine/freio no 74HC4067.
    - docs/INPUTS_PINOUT.md/.en.md: a seção 'O preço dessa troca' dizia que o
    INT do MCP23017 'está reservado no GPIO14 e vale a pena fiar' — contradizia
    a própria seção 4 do mesmo documento (e o board_config.h), que já
    documentava a remoção dessa reserva por ser pino inacessível. Também
    reforça em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
    [board_config.h, mux_test.cpp]
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2026-09-30 fix: reduz TX power do WiFi pra 11dBm (mitigacao de brownout no boot)
    Achado analisando o loop de reset relatado no Windows (USB conectando e
    resetando em loop, antes mesmo de abrir a serial): o firmware nunca
    limitava a potencia de TX do radio, entao WiFi.begin() sobe no maximo
    (WIFI_POWER_19_5dBm) bem em cima do boot, logo depois de MCP23017 +
    74HC4067 + WS2812 ja terem inicializado — e' o maior pico de corrente do
    firmware inteiro, na pior hora possivel pra uma porta/cabo USB com pouca
    folga.
    WiFi.setTxPower(WIFI_POWER_11dBm) antes do primeiro WiFi.begin() reduz
    bastante esse pico sem prejudicar alcance de mesa. So precisa ser setado
    uma vez no boot — diferente do setSleep(), TX powe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
    [main.cpp]
2026-09-30 fix: start engine (C11) e seu LED sao comum-anodo, nao comum-catodo
    BOARD_MUX_ACTIVE_HIGH_MASK 0x0000 -> 0x0800 e BOARD_START_ENGINE_LED_ACTIVE_LOW
    false -> true. O botao iluminado montado na bancada e' comum-anodo (COM ->
    3,3V) — a 'variante B' ja documentada em docs/INPUTS_PINOUT.md secao 11 —
    mas o board_config.h ainda estava configurado pra variante A (comum-catodo),
    causando os dois sintomas relatados: LED do Start Engine aceso com a
    ignicao em OFF (deveria apagar), e o botao 18 invertido no HID (aparecia
    pressionado em repouso, soltava ao apertar).
    Seguro trocar pra active-high porque o usuario confirmou o pull-down
    externo de ~4,7 kOhm entre C11 e GND ja esta soldado — sem ele,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
    [board_config.h]
2026-09-30 fix: matriz 8x8 saindo espelhada (eixo X) - novo flag BOARD_MATRIX_MIRROR_X
    Sintoma relatado: caracteres enviados pelo SimHub saem com a lateralidade
    trocada (ex.: '2' aparece parecido com 'S') — espelhamento horizontal
    uniforme, diferente do problema classico de zigzag de fiacao (que da
    imagem quebrada, nao um caractere reconhecivel so invertido).
    O remapeamento da matriz em main.cpp so tinha MATRIX_SERPENTINE (corrige
    fiacao interna em zigue-zague do painel) e era uma constante local, nao
    configuravel via board_config.h. Motivo real e' independente: o painel
    esta montado/ligado com o DIN do lado oposto do esperado, espelhando a
    imagem toda no eixo horizontal, por cima do zigue-zague.
    M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
    [board_config.h, main.cpp]
2026-09-30 fix: freio de estacionamento (botao 19) agora e' pulso de toggle, nao nivel
    Achado ao revisar se handbrake/chaves caca/ignicao estao com a logica
    certa pro Euro/American Truck Simulator (pergunta direta do usuario). O
    freio JA TINHA uma especificacao decidida com o usuario faz tempo
    (docs/INPUTS_PINOUT.md secao 7): o bind padrao de freio de estacionamento
    desses jogos e' TOGGLE (alterna a cada aperto), mas o manete fisico e' um
    switch de 2 posicoes ESTAVEIS — espelhar o nivel direto no HID faz o jogo
    ver 'segurar o botao', nao 'apertar duas vezes', entao o freio nao
    desengata quando o manete volta pra cima.
    Essa especificacao nunca foi implementada: a integracao HID original
    (secao 10, ja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
    [main.cpp]
2026-09-30 refactor: generaliza pulso de toggle pra lista configuravel (TOGGLE_PULSE_IDS)
    updateHandbrakePulse() (especifico do freio) vira updateTogglePulses(),
    dirigido por um array TOGGLE_PULSE_IDS[] em vez de logica hardcoded pra
    um unico InputId. Motivo: o mesmo problema do freio de estacionamento
    (switch de posicao mantida vs bind de jogo que espera toggle-por-aperto)
    pode aparecer em qualquer chave caca, dependendo da acao a que ela for
    bindada no jogo (farol alto, pisca-alerta, etc.) -- com isso, adicionar
    outra entrada e' uma linha no array, nao uma funcao nova copiada/colada.
    Nenhuma mudanca de comportamento pro freio (continua o unico item na
    lista hoje). Build completo (9 envs) OK. Precisa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
    [main.cpp]
2026-09-30 fix: chaves caca (botoes 20-23) tambem viram pulso de toggle
    Decisao (a pedido do usuario, que delegou o julgamento por ser a primeira
    buttonbox com chaves dele): as 4 chaves caca entram em TOGGLE_PULSE_IDS
    junto com o freio. Motivo -- praticamente todo acessorio de caminhao no
    Euro/American Truck Simulator (pisca-alerta, giroflex, luz de teto,
    travamento de diferencial, farol extra, etc.) e' um bind de TOGGLE no
    jogo, e o tipo de chave escolhido pro projeto (alavanca/bat, fica na
    posicao) e' justamente pra esse uso -- nivel teria o mesmo problema ja
    corrigido no freio (jogo ve 'segurando', nao alterna de volta quando a
    chave volta de posicao).
    INPUT_IGNITION_ON/_IGN continuam nivel de prop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
    [main.cpp]
2026-09-30 fix: ignicao ON (botao 16) tambem vira pulso de toggle
    Usuario trouxe a info correta direto do menu de Teclas e Botoes do
    ETS2/ATS: o jogo TEM um bind nativo pra isso -- 'Ligar/Desligar
    Eletricidade do Motor' (liga painel/GPS sem girar o motor) -- separado de
    'Ligar/Desligar Motor' (partida de verdade). Ambos sao toggle no jogo.
    Isso invalida minha suposicao anterior de que INPUT_IGNITION_ON nao tinha
    bind nativo e por isso podia ficar nivel.
    INPUT_IGNITION_ON entra em TOGGLE_PULSE_IDS: a chave fisica (posicao 2, tipo
    scooter) e' mantida, entao tem o mesmo problema do freio/chaves caca.
    Seguro fazer essa troca porque updateStartEngineLed() le
    inputs_get_state(INPUT_IGNITION_ON) direto (nao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
    [main.cpp]
2026-09-30 docs: registra uso pretendido dos botoes 17 (IGN) e 18 (Start Engine)
    Comentario-only, nenhuma mudanca de comportamento -- os dois ja estavam
    corretos como nivel (ambos fisicamente momentaneos). So documenta a
    decisao do usuario sobre pra que cada um serve, pra quem mexer no codigo
    depois nao precisar adivinhar:
    - INPUT_IGNITION_IGN (Botao 17): partida de verdade, bind 'Ligar/
    Desligar Motor' do ETS2/ATS -- e' o giro da propria chave.
    - INPUT_START_ENGINE (Botao 18): botao iluminado avulso, sem destino
    fixo -- livre pra outro jogo de corrida ou qualquer funcao futura.
    Build completo (9 envs) OK. Nada novo pra gravar (comentario-only).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
    [main.cpp]
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2026-09-30 fix: matriz corrigida com dado real do MATRIXWALK (girada 180 graus, fiacao reta)
    Medicao com o comando MATRIXWALK (nao mais chute por forma de caractere,
    que nao convergia): phys=0 = canto inferior direito; phys 0->7 anda pra
    esquerda na fiada de baixo; phys=8 = canto superior-direito da fiada de
    cima (nao em cima do phys=7) -- confirma fiacao RETA (nao serpentina) e
    painel equivalente a girado 180 graus.
    Mudancas:
    - BOARD_MATRIX_SERPENTINE: true -> false (fiacao confirmada reta).
    - Novo BOARD_MATRIX_MIRROR_Y: espelhamento vertical, junto com o
    MIRROR_X ja existente -- os dois juntos equivalem a phys = 63 - i.
    - main.cpp aplica os tres flags na ordem: mirror_x, mirror_y, depois
    serpent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
    [board_config.h, main.cpp]
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2026-09-30 fix: matriz estava de cabeca pra baixo -- desliga BOARD_MATRIX_MIRROR_Y
    Usuario confirmou com foto: MIRROR_X=MIRROR_Y=true deixou a imagem quase
    certa mas invertida verticalmente (bandeirinha do '1' saiu embaixo em vez
    de em cima). O eixo horizontal (MIRROR_X) ja estava certo; so o vertical
    estava sobrando. BOARD_MATRIX_MIRROR_Y: true -> false.
    Formula final: phys = y*8 + (7-x), com SERPENTINE=false.
    Build completo (9 envs) OK. Gravado por OTA nesta sessao.
    Claude-Session: https://claude.ai/code/session_01Jq2EdB1Vv8gVpZsd9ChNh1
    [board_config.h]
2026-09-30 fix: matriz ainda espelhada horizontalmente -- desliga BOARD_MATRIX_MIRROR_X
    Usuario confirmou com fotos (1, 2, 4): depois do fix vertical anterior, o
    vertical ja estava certo, mas o horizontal continuava espelhado (2 e 4
    apareciam invertidos esquerda-direita). Como MIRROR_X e MIRROR_Y sao
    aplicados a x e y de forma totalmente independente no codigo, desligar
    MIRROR_X nao arrisca voltar o problema vertical ja corrigido.
    BOARD_MATRIX_MIRROR_X: true -> false. Com isso os 3 flags ficam todos
    false (SERPENTINE=false, MIRROR_X=false, MIRROR_Y=false) -- fiacao real
    desta bancada e' identidade pura (phys = i), sem nenhum remapeamento.
    Co-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
    [board_config.h]
2026-09-30 docs: corrige comentario sobre a medicao do MATRIXWALK (leitura enviesada)
    O comentario ainda descrevia o resultado do MATRIXWALK (MIRROR_X=MIRROR_Y=
    true) como a config final -- ficou desatualizado assim que os caracteres
    reais mostraram que o certo era tudo false. Provavel causa: a caixa foi
    lida em orientacao diferente (~180°) da montagem normal durante aquele
    teste especifico. Registra isso pra quem for usar o MATRIXWALK de novo no
    futuro nao cair na mesma pegadinha -- e deixa explicito que comparacao de
    caracteres reais tem prioridade sobre a leitura crua se os dois divergirem.
    Build completo (9 envs) OK. Sem mudanca de comportamento (comentario-only).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
    [board_config.h]
2026-10-03 feat: matriz/fita apagam com ignicao OFF + fix: portal de WiFi + gesto alternativo com a caixa fechada
    1) Matriz/fita WS2812 agora apagam quando INPUT_IGNITION_ON esta OFF,
    igual o LED do Start Engine ja fazia (mesma fonte: inputs_get_state).
    Nem SimHub nem a animacao de idle aparecem nesse estado -- decisao do
    usuario, pra bater com um painel de carro de verdade. MATRIXWALK
    continua funcionando com a ignicao OFF de proposito (diagnostico
    manual nao deveria depender de chave).
    2) BUG REAL achado investigando porque o usuario nao conseguia trocar de
    rede numa casa nova: a atribuicao do retorno de startConfigPortal() em
    modo nao-bloqueante direto pra portalAtivo. Em modo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
    [main.cpp]
2026-10-03 feat: remove WiFi hardcoded de secrets.h -- rede so' via portal, persistida no NVS
    Pedido direto do usuario: levou a button box pra casa do irmao, quer
    "limpar" a rede antiga e nao quer mais nenhuma rede fixa no
    firmware/repositorio -- quer que seja 100% configuravel.
    Mudancas em src/main.cpp:
    - setup(): WiFi.begin(WIFI_SSID, WIFI_PASS) -> WiFi.begin() sem
    argumentos. Reconecta na ULTIMA rede salva no NVS do proprio ESP32
    (persistido automaticamente pelo driver WiFi a cada WiFi.begin(ssid,pass)
    bem-sucedido -- e' assim que o portal de configuracao grava a escolha).
    - wifiKeepAlive(): mesma troca no retry loop.
    - Combo alternativo do portal trocado de Push button 1+11 pra Push
    button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
    [main.cpp]
2026-10-03 feat: indicacao visual de boot e de modo de configuracao de WiFi
    Pedido do usuario: faltava algum sinal rapido nos LEDs de "a placa ligou"
    e de "entrou no modo de setup do WiFi".
    1) Flash de boot: se a ignicao JA estiver ON quando a placa liga/reseta
    (plugou o USB com a chave ligada), pisca matriz+fita em branco por
    ~150ms logo no setup(), antes do WiFi subir. So dispara com ignicao ON
    -- com a chave desligada, apagado continua sendo o estado esperado
    (nao um erro), entao nao faz sentido piscar.
    2) Indicador do portal: enquanto portalAtivo (BOOT ou combo de botoes
    segurados 5s), matriz+fita respiram em azul puro (periodo ~2s,
    triangular 40-255 de brilho) em vez de mostrar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
    [main.cpp]
2026-10-03 fix: self-test de boot roda SEMPRE, nao so com ignicao ligada
    Usuario pediu: mesmo com a chave desligada, queria alguma animacao/check
    rapido nos LEDs confirmando que a placa ligou, apagando no final.
    Flash de boot (setup()) deixa de ser condicional a inputs_get_state(
    INPUT_IGNITION_ON) e vira uma sequencia curta sempre executada:
    vermelho -> verde -> azul -> branco (~120ms cada, ~0,5s total) e apaga no
    fim. Com ignicao desligada, o apagar final já deixa a matriz/fita no
    estado esperado (loop() mantem apagado); com ignicao ligada, o loop()
    assume dali pra SimHub/idle normalmente.
    Build completo (9 envs) OK. Gravado por OTA nesta sessao.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
    [main.cpp]
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
